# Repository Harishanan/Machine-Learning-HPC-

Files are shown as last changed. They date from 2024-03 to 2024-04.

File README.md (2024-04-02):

<h1 align="center">High-Performance Computing System</h1>

## Table Of Contents
- [I. About The Project](#i-about-the-project)
- [II. Built With](#ii-built-with)
- [III. Introduction](#iii-introduction)
- [1. System Design And Architecture](#1-system-design-and-architecture)
- [2. Technology Research:](#2-technology-research)
  - [2.1 Operating System Selection:](#21-operating-system-selection)
    - [2.1.1 Install Operating System in Head Node](#211-install-operating-system-in-head-node)
    - [2.1.2 Install Operating System in Compute Node](#212-install-operating-system-in-compute-node)
  - [2.2 Power Management](#22-power-management)
  - [2.3 Network Interconnect:](#23-network-interconnect)
  - [2.4 Cooling Calculations](#24-cooling-calculations)
    - [2.4.1.	3D Model](#2413d-model)
- [3. System Construction:](#3-system-construction)
- [4. Housing and Cooling Solutions:](#4-housing-and-cooling-solutions)
  - [4.1. Original Design For The HPC Case](#41-original-design-for-the-hpc-case)
  - [4.2. Problems Encountered](#42-problems-encountered)
  - [4.3. Chosen Shell](#43-chosen-shell)
  - [4.4. Other alterations](#44-other-alterations)
  - [4.5 Design reflection and future improvements](#45-design-reflection-and-future-improvements)
  - [4.6. Time impairment](#46-time-impairment)
  - [4.7.  Material acquisition](#47--material-acquisition)
  - [4.8. Ventilation](#48-ventilation)
  - [4.9. Change in requirements](#49-change-in-requirements)
  - [4.10 Reflection](#410-reflection)
- [5. System Configuration](#5-system-configuration)
  - [5.1. Networking](#51-networking)
    - [5.1.1. Open-SSH connection](#511-open-ssh-connection)
    - [5.1.2 Network File System (NFS)](#512-network-file-system-nfs)
  - [5.2. Power on and off function in HPC](#52-power-on-and-off-function-in-hpc)
  - [5.3. CPU frequency scaling](#53-cpu-frequency-scaling)
  - [5.4 CPU Overclocking](#54-cpu-overclocking)
- [6.Software Installation](#6software-installation)
  - [6.1. PXE Server Configuration on Ubuntu](#61-pxe-server-configuration-on-ubuntu)
  - [6.2. Cluster Package Management Script](#62-cluster-package-management-script)
    - [6.2.1. Setup](#621-setup)
    - [6.2.2. Usage](#622-usage)
  - [6.3. SLURM Configuration](#63-slurm-configuration)
  - [6.4. Apptainer Configuration](#64-apptainer-configuration)
  - [6.4.1. Reasons for Using Apptainer](#641-reasons-for-using-apptainer)
  - [6.5. Configure Prometheus and Grafana](#65-configure-prometheus-and-grafana)
  - [Importance of Grafana and Prometheus in HPC Context](#importance-of-grafana-and-prometheus-in-hpc-context)
  - [6.6. Monitoring Energy Consumption and Efficiency with Prometheus](#66-monitoring-energy-consumption-and-efficiency-with-prometheus)
- [7. Task Implementation:](#7-task-implementation)
  - [7.1. How to Create Machine Learning for Predict Crypto Currencies](#71-how-to-create-machine-learning-for-predict-crypto-currencies)
  - [7.2. Implementation of Cryptocurrency Price Prediction Application](#72-implementation-of-cryptocurrency-price-prediction-application)
- [8. Performance Evaluation: Develop a strategy for evaluating HPC system performance.](#8-performance-evaluation-develop-a-strategy-for-evaluating-hpc-system-performance)
- [9. Software and OS Maintenance:](#9-software-and-os-maintenance)
  - [9.1. The Critical Role of Software and OS Maintenance](#91-the-critical-role-of-software-and-os-maintenance)
    - [9.1.1. Software Maintenance for Enhanced Performance and Reliability:](#911-software-maintenance-for-enhanced-performance-and-reliability)
    - [9.1.2. OS Maintenance for Stability and Security:](#912-os-maintenance-for-stability-and-security)
    - [9.1.3. Impact of Maintenance on Software Complexity and Maintenance Performance:](#913-impact-of-maintenance-on-software-complexity-and-maintenance-performance)
  - [9.2. Setting Up a System for Software and Operating System Updates Using Cron and Git](#92-setting-up-a-system-for-software-and-operating-system-updates-using-cron-and-git)
  - [9.3. Create Man Page](#93-create-man-page)
- [10. Conclusion](#10-conclusion)
- [IV. References](#iv-references)
- [V. Authors](#v-authors)

# I. About The Project
The provided documentation outlines the comprehensive process undertaken by Team 0 for the design of a High Performance Computing (HPC) system as part of the Advanced Computer Engineering Module for the Computer Engineering Program at the University of Greenwich for the academic year 2023/24. This report guides the reader through a detailed step-by-step procedure encompassing both hardware and software aspects of the project. By following this documentation, readers will gain insights into the systematic approach employed by the team, enabling them to replicate and create their own HPC systems.  

The video documentation link can be found [here](https://www.youtube.com/watch?v=lD17i18koeo)

# II. Built With
- [Ubuntu](https://ubuntu.com/)
- [OpenSSH Server](https://ubuntu.com/server/docs/service-openssh)
- [Netwrok File Storage](https://ubuntu.com/server/docs/service-nfs#:~:text=NFS%20allows%20a%20system%20to,if%20they%20were%20local%20files.)
- [Slurm](https://slurm.schedmd.com/documentation.html)
- [Apptainer](https://apptainer.org/)
- [Grafana](https://grafana.com/)
- [Prometheus](https://prometheus.io/)
- [Python](https://www.python.org/)
- [Keras](https://keras.io/)
- [Scikit-learn](https://scikit-learn.org/stable/)
- [Pandas](https://pandas.pydata.org/)
- [Numpy](https://numpy.org/)
- [Yahoo Finance](https://finance.yahoo.com/quote/ORGN/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)

# III. Introduction

HPC (High Performance Computing) involves combining the computational capabilities of multiple computers to achieve significantly greater performance than individual systems. It can be referred as Cluster Computing, where a network of two or more computing devices collaborates towards a shared computing objective. This network operates on the principle of parallel processing, which entails distributing complex tasks among two or more processors (CPUs) to expedite their execution.

This documentation outlines the procedures undertaken to construct a comprehensive HPC system utilizing five motherboards, with one serving as the head node and four as compute nodes. The HPC is intended to run a cryptocurrency prediction application capable of forecasting Bitcoin, Ethereum, and Binance Coin (BNB) prices using its datasets. Additionally, it provides a detailed, step-by-step guide for configuring services and necessary configuration files to facilitate parallel processing and establish connections between nodes.

# 1. System Design And Architecture 

Before commencing the project design process, a comprehensive file containing all specifications was compiled. This file proved invaluable throughout the project, aiding in power and cooling calculations and enhancing our understanding of the system. [Specification of all the components can be found here!](hardware.md)

Initially, a design concept was developed, featuring two cases where motherboards were stacked vertically, each housing five motherboards. These motherboards would be powered by a 750W Power Supply Unit (PSU). Additionally, this design would be connected to a Single Board Computer (SBC), serving as the head node. Figure 1 illustrates the initial design idea.

<div align="center">

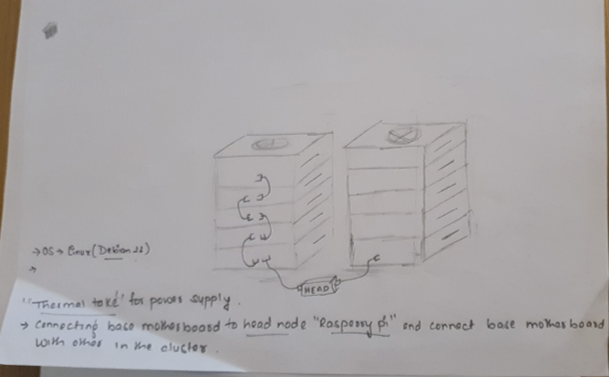
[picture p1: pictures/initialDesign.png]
Initial_Design_Sketch
<br>
      <b>Figure 1: Initial Design Sketch</b>
      <br>

</div>

But the initial idea was dropped, as it was realised that single board computer is not required, as motherboard with a wifi adapter was powerful than a single board to work as a head node. because of the time constraint, only one case was designed with 5 motherboards, and PSU was also changed because of technical issues. Therefore the design was finalised which is similar to the initial idea but only one case with five motherboard were used and the position of fans were moved to the side  which is much efficient place which will be discussed below. The final design is depicted in figure 2.

However, the initial concept was abandoned upon the realization that a single motherboard with a Wi-Fi adapter was more powerful compared to a single board computer for serving as the head node. Due to time constraints, only one case was designed to accommodate five motherboards, and the PSU was replaced due to technical challenges. Consequently, the finalized design closely resembled the initial idea, with a single case housing five motherboards. Additionally, the positioning of fans was relocated to the side, which was deemed more efficient. The final design is depicted in Figure 2.

<div align="center">

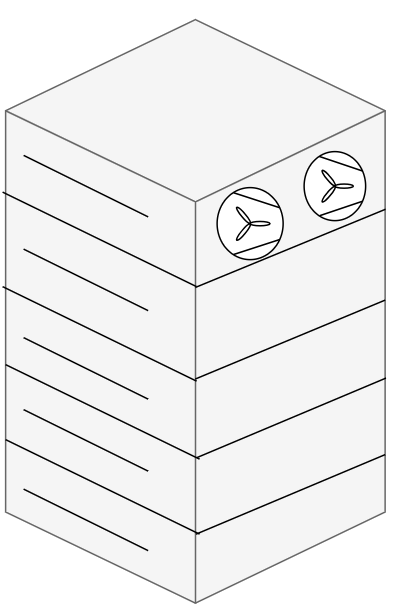
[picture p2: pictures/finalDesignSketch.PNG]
Final_Design_Sketch
<br>
      <b>Figure 2: Final Design Sketch</b>
      <br>

</div>

Once the basic structure of the HPC was conceptualized, technical research was initiated to gather essential information and conduct necessary calculations.

# 2. Technology Research: 

## 2.1 Operating System Selection: 

Initially, an attempt was made to determine which operating system the ASUS CS-B motherboard supports. However, the information available suggests that the ASUS CS-B is only compatible with Ubuntu 13.10, as indicated in the provided image.

Os
Figure 3: OS Compatibility of Asus CS-B 

### 2.1.1 Install Operating System in Head Node

1. Once the operating system was determined, below steps are followed to install ubuntu desktop 13.10:
      - Downloaded the Ubuntu Desktop from the official Ubuntu website (https://old-releases.ubuntu.com/releases/13.10/). As Intel processor is used, PC (Intel x86) desktop image is chosen when downloading the image.
      - Created a bootable USB drive using Rufus.
      - Booted the motherboard from the USB drive.
      - Followed the installation wizard to install Ubuntu Desktop on the system.

                  sudo apt update                                           
            
                  sudo apt upgrade
    
- The head node serves as a central control unit in an HPC environment, orchestrating and managing the entire cluster. Its primary purposes include task scheduling, resource allocation, and overall coordination of computational tasks within the cluster. By installing      the Ubuntu Server and setting the default target to multi-user mode optimize resource allocation, conserving RAM and CPU resources by eschewing unnecessary graphical sessions. This ensures that the head node operates efficiently, enabling it to efficiently manage and    oversee the computational workload of the entire HPC cluster.
  
            To install Ubuntu Server  : sudo apt install ubuntu-server
            To disable GUI            : sudo systemctl set-default multi-user.target
     
Although the documentation states that the ASUS CS-B motherboard can only run Ubuntu 13.10, a brief test was run to see how the motherboard would react to installing Ubuntu 24.04 (Nobel Numbat), a more recent version of the operating system. The Ubuntu 24.04      
operating system ran on the system very well, with no noticeable glitches. This surprising finding prompted more investigation into the motherboard's compatibility with the latest Ubuntu versions. 
Although documentation indicates otherwise, one plausible explanation for Ubuntu 24.04's successful running on the ASUS CS-B motherboard could be the hardware compatibility enhancements included in later Ubuntu editions. The Ubuntu operating system is continuously improved and optimised by its developers throughout time to improve compatibility with a wider variety of hardware setups. Because of this, more recent versions of Ubuntu might by nature support a greater range of motherboards, including the ASUS CS-B. Moreover, improvements in system libraries, kernel updates, and device drivers in Ubuntu 24.04 can also be responsible for its smooth operation on the ASUS CS-B motherboard. These updates might take care of any compatibility problems that earlier motherboard models might have had, making it possible to use current Ubuntu editions more smoothly.

After noticing that Ubuntu 24.04 operated steadily on the ASUS CS-B motherboard, the group chose to switch from Ubuntu 13.10 to this more recent version. This choice was driven by the goal of utilising Ubuntu 24.04's most recent software features, security updates, and hardware compatibility changes to provide the best possible computing environment for the team's activities.

### 2.1.2 Install Operating System in Compute Node

The process of installing the operating system on a compute node is similar to that of the head node, with the exception that it is not required the installation of Ubuntu Server specifically.

## 2.2 Power Management

   Following a thorough examination of individual components, research has been conducted to determine the optimal power distribution among them. Initially, the plan was to utilize two 750W Power Supply Units (PSUs). However, due to technical malfunctions in one of the PSUs, the decision has been made to employ smaller PSUs for each motherboard separately. The power consumption of each hardware component is provided below for reference.
  
   |      Components        |     Power Consumption (approx)       |       Description        |
   |------------------------|-----------------------------|--------------------------|
   |Asus CS-B Intel Core i3 4th Gen | 25W - 40W       | CPU Power Management can be handeled directly from BIOS. It provides subitems that allows to manipulate the CPU ratio and feature.|
   |SAMSUNG V-NAND 500GB SSD| 3W (Active), 50mW (idle)|Each Motherboard will be connected to one of this SSD which can be powered by a same PSU.|  
   |NVIDIA QUADRO           |    45W (Max.)           |Only one of the GPU will be used in the entire system which will be connected to the head node. |        

   |Power Supply Unit (PSU)| Capacity | Description|
   |---|---|---|
   |FSP220-50LC|220W (total output) | This PSU has a maximum wattage of 60W. And the sum of the power requirements for all the components connected to the PSU should not exceed 220W. |

* Active Power Consumption:

        CPU: 25W - 40W
        SSD: 3W
        GPU: 45W
        Total Active Power Consumption = CPU + SSD + GPU
        = (25W - 40W) + 3W + 45W
        = 73W - 88W

* Idle Power Consumption (Assuming SSD and GPU are in idle state):

* Active Power Consumption:

        CPU: 25W - 40W
        SSD: 3W
        GPU: 45W
        Total Active Power Consumption = CPU + SSD + GPU
        = (25W - 40W) + 3W + 45W
        = 73W - 88W

* Idle Power Consumption (Assuming SSD and GPU are in idle state):

* Power Supply Unit (PSU) Capacity:

        Total Output Capacity: 220W
        Maximum Wattage: 60W

Therefore, a single PSU in our system will be connected to one motherboard, one SSD, and one graphics card. The total power consumption of the system should not exceed the PSU capacity.

The system is expected to consume between 73W - 88W during active use and between 25.05W - 40.05W when idle. Although a single 220W PSU could theoretically handle the load for two motherboards, practical constraints like cable and port limitations restrict each PSU to power only one motherboard in our setup

## 2.3 Network Interconnect:

There are several interconnect technologies available for establishing connection in a cluster computing with their own strength and specefic use-cases. Some of them are :

1. **Infiniband** : Computer Networking communication standard used in high-performance computing that features high throughput and very low latency. It supports Remote Direct Memory Access(RDMA), which means the ability to access host memory directly without CPU intervention. Infiniband is widely used in supercomputer clusters and it is preferred network interconnection technology for GPU servers.
2. **NVIDIA NVLink** : World's first high-speed GPU interconnect technology that can connect two graphics card , with low latency, and high bandwidth. It is ideal for the system that uses NVIDIA graphics card, such as those in deep-learning and GPU accelerated computing. It is not best option for our project,as it is only compatible with NVIDIA graphics card and we will be using intel graphics card for our HPC.
3. **Intel Omni-Path Architecture(OPA)** : OPA is communication architecture developed by intel which aims for low communication latency, low power consumption and a high throughput. It is often used for HPC application with Intel processor. OPA directly competes with infiniband.
4. **Ethernet** : Ethernet is one of the commonly used interconnect technology because of its versatility, scalability and compatibility.It migh not provide same low-latency level as specialised interconnect like infiniband but it provides various speed, ranging from 10 megabyte to 100 gigabyte per second.    

The type of interconnect technology one needs lies on what kind of system they are building and what kind of interconnect is compatible with the system. For our system, specefication and hardware is given above.

For this project, Ethernet cables will be utilized due to their accessibility and sufficient speed for project requirements. These cables will serve dual purposes: data transfer and network bridging. The motherboard provided includes two Ethernet ports, both of which will be utilized for interconnecting nodes.

The head node will establish connections with all other nodes via a switch. Two switches will be employed: one for interconnecting all nodes to facilitate data transfer, and the other to distribute internet connectivity from the head node to all compute nodes. 

By default, one of the ports is enabled. However, to activate the second port, users must adhere to the following steps:

            Reboot the motherboard 

            Press the 'F2' or 'Del' button to access the BIOS settings 

            Navigate to Advanced settings using arrow keys.

            Proceed to Network Interface Stack Setting

            Enable the Second Interface named "Retalke Interface" (most of the cases, name may vary)

            Esure that your "Intel Interface" is also enabled.

Once the steps are followed and both interfaces are activated, users can proceed to configure each interface to perform specific tasks. Detailed instructions can be found in the following link: [Configuring Interface using Nm-Connection-Editor](https://github.com/TeachingMaterial/ace-2023_-team-0/tree/documentation/nm-connection-editor-Harishanan)

Ethernet cables were manually crimped for this project, adhering to the Registered Jack 45 (RJ-45) standard. The figure 4  illustrates the color standard for RJ-45 cables..
<div align="center">

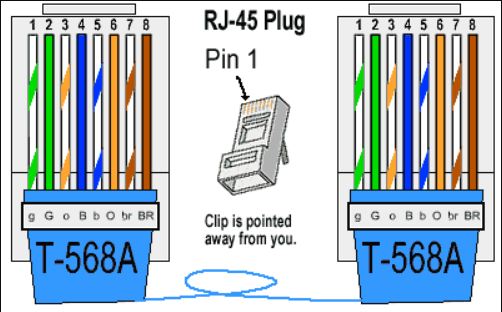
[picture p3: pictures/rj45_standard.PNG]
RJ-45 Standard
<br>
      <b>Figure 4: RJ-45 Standard</b>
      <br>
</div>

Step wise Step  process is shown in figure 5 below:
<div align="center">

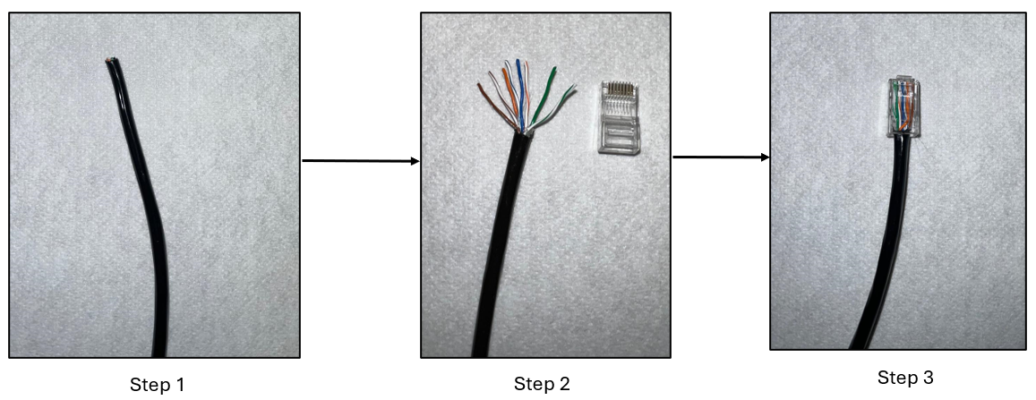
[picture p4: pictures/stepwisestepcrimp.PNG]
Ethernet-Crimp
<br>
      <b>Figure 5: Step by Step Ethernet Cimp</b>
      <br>
</div>

System is expected to consume between 73W - 88W during active use and between 25.05W - 40.05W when idle. Although a single 220W PSU could theoretically handle the load for two motherboards, practical constraints like cable and port limitations restrict each PSU to power only one motherboard in our setup

## 2.4 Cooling Calculations

Cooling calculations were conducted to determine the necessary airflow for ordering the appropriate fan. This involved performing a simple arithmetic calculation, the details of which can be found in the [this file here.](coolingcalculation.md). 

### 2.4.1.	3D Model 
 The selection of the fan was made with careful consideration of various factors, and a dual-fan system was chosen. Two fans are positioned at the front of the case to intake cool air, while another two are situated at the back to expel hot air as depicted in Figure 1. This configuration creates an airflow pattern that helps maintain optimal temperatures for all components.

   Additionally, the CPU fan, which is attached to the motherboard, provides active cooling for the CPU. Moreover, the GPU and power supply unit also have built-in fans for additional cooling.
  <div align ="center">

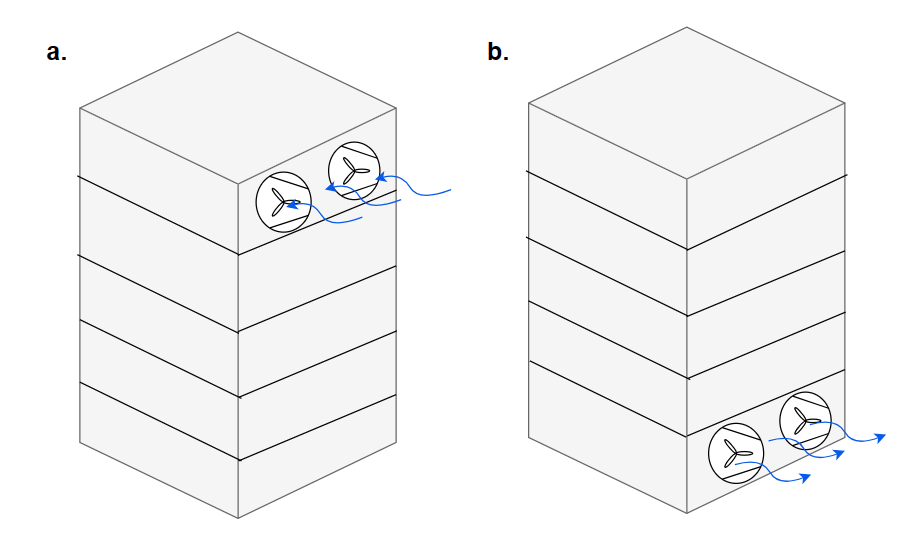
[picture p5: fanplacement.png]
Fan Placement
   <br>
   <b>Figure 6: 3D Model of Case with the fan where a) represents the front 3D view and b) represent the back 3D view </b>
   <br>
  </div>

# 3. System Construction:

Following the completion of all technical research, a preliminary outline for the basic system construction was created. This step was crucial to ensure that once the case was constructed, the components could be assembled in each shelf according to the designated layout. Notably, since the head node includes a GPU whereas the compute nodes do not, additional clearance was required to prevent overcrowding and ensure proper placement of the motherboard. The initial design for a shelf, which encompasses the motherboard, PSU, and SSD, is depicted in the figure 7 below.

  <div align ="center">

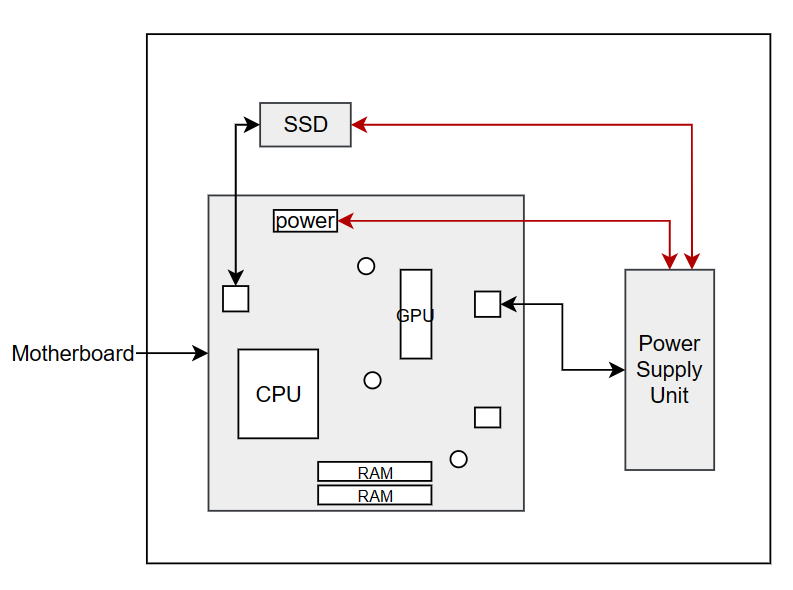
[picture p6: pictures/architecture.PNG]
Architecture
 <br>
   <b>Figure 7: 2D Structure of the shelf with all the components.</b>
   <br>

</div>

Each motherboard was equipped with a 500 GB SSD and 2 * 8 GB RAM, providing sufficient resources for efficient task execution. With four compute nodes in use, this configuration ensures optimal performance. Additionally, the head node can leverage the resources of all nodes simultaneously when executing tasks.

During the layout creation process, careful consideration was given to various requirements such as cooling, power supply, placement dimensions, and more. All calculations pertaining to these requirements have been documented in detail below.

# 4. Housing and Cooling Solutions: 

## 4.1. Original Design For The HPC Case
The original design for the case consisted of 3D printing of all components needed. This included the shelves, floor, roof, and side/back panels of the case. Multiple aspects have to be considered when designing the case such as the components requirements, ventilation, and accessibility. All original shelf and case piece that have been uploaded were designed to be durable and well ventilated and were easily connected together using a pin system

## 4.2. Problems Encountered
While waiting to receive the initial components from 3d printing I was informed that it would take to long to 3d print all my required components as there were many other students looking to 3d print components at this time Aswell. To solve this issue, we decided to order the shell of our case and print the brackets and laser cut the shelves as well as the front and back panels in stead of printing all the components

## 4.3. Chosen Shell  
The case we ordered was a 21U tall server racking system which was perfect for the purpose of our projects. It came with slots all down the left and ride side of the case which ensured enough ventilation for the fans to disperse the heat 

<div align="center">

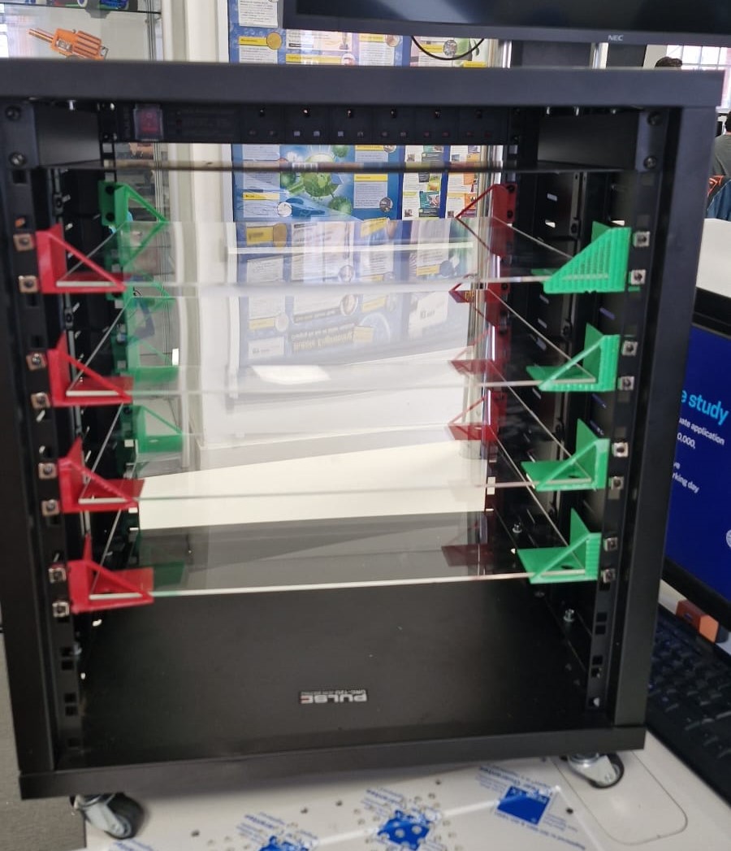
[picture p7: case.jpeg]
Shell
<br>
<b>Figure 8:Case</b>
<br><br>

</div>

The 1U brackets were 3d printed in order to hold the acrylic shelves that were laser cut. They were mounted in the holes that were ment for the racking system of the case. An extension cord was placed at the back and mounted to the top of the case. Whis acted as a way to limit the amount of cables that would exit the case. Instead, we could power each of the motherboards power sources internally 

<div align="center">
  
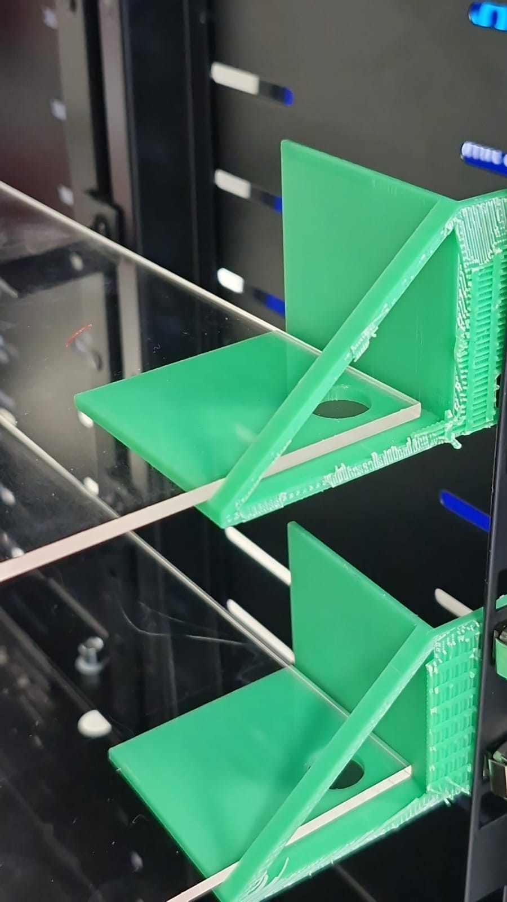
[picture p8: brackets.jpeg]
<br>
<b>Figure 9:3D printed brakets </b>
<br><br>

</div>

The front and back of the case was laser cut in acrylic with 120x120 fan holes at the base and the top in order to mount the fan to then in a way that allowed them to get a strong enough air pull. Hence the small circles that fill the 120x120 frame. the back panel was made to be slightly smaller to allow room for the extension cord 

<div align="center">

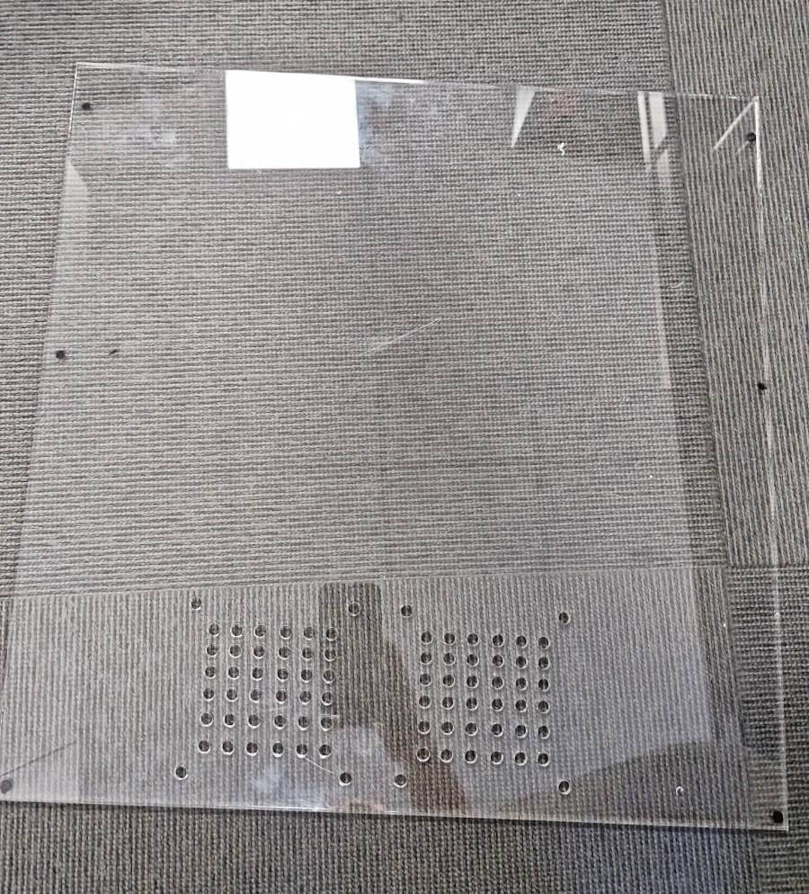
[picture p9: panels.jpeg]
<br>
<b>Figure 10:3D back panel of case  </b>
<br><br>

</div>

## 4.4. Other alterations
Rubber feet will be used on the motherboards and the SSDs to limit the directs contact onto the shelves to allow air underneath the boards when necessary. The extension cable will run down the side of the case into an outlet. The power button will drill through the roof of the case to allow Instant power to the application we have also decided to cover the back of the case to limit the light inside the case to utilize the led fans. All power supply will plug directly into the extension cord build into the case

## 4.5 Design reflection and future improvements 
During the course of this assignment there have been a few development problems and issues that arose in regard to the specific design of the case such as the time impairment, material acquisition, ventilation and change in requirements. In this report I will discuss how each of these problems were analyzed and resolved to display a design that fit the requirements of the projects while also remaining affordable and simple to construct.

## 4.6. Time impairment 
The first and possible largest issue we faced in constructing the case was time. As we had a fixed amount of time to build and submit the Hpc the case had to be completed in about a month and a half. My first idea was 3D printing the part required to build the frame/shelfing unit. After sending my designs of to be printed I was told that all part would take over 80 das as there was over 65 pieces to print along with other student needing to use the printing facilities as well.to work around this problem I decided that purchasing a frame could be cheaper and less time consuming as well as having more stability. This way I could focus more on altering the internal of the case as well as making a front and rear for the frame. This cut the time to create a case by at least a month allowing more time for alterations if need be 

## 4.7.  Material acquisition 
An issue arose with the materials as some materials were ordered before the time issues were realized. This issue was fixed by ordering the correct components and altering the lengths of some of the cables needed like the ethernet cable and the power cable along with some cable management. I mention these issues as it highlighted the need to double-check the design before ordering any components as well as communicating with my teams to avoid these mistakes happening in the future.

## 4.8. Ventilation
The ventilation of the case was considered from the very beginning as it essential to keep the system cool under prolonged periods of time.  With 5 motherboards being used in sync I decided to go with a 2 in 2 out fans system. 2 fans would take air in at the top front of the case and 2 would blow air out of the case at the bottom rear. This would allow decent air flow that would keep a steady current around the case. Temperature sensors inside the case can monitor how hot the components get and alert the user if the temperature exceeds the recommended limit.

## 4.9. Change in requirements 
Throughout the course pf this project there were a number of alterations that needed to be made to counter errors in judgement as well as new components that needed to be added to achieve complete networking between the boards. By altering the size of the shelves and by utilizing the space in the side of the case for storing the wires, all new components and power sources fit as needed 

## 4.10 Reflection 
If I were to design this case again, I believe there are a few changes that could be made. I think the biggest change I would make is I would have made holes across the laser cut shelves as it would increase the ventilation in the case however if I did this, I would make the shelf out of wood as with to many holes cut the structural integrity would be compromised and they may not be able to hold the components at the current thickness. By changing the material to wood and increasing the thickness of the shelves, adding the holes will not impair the performance. It is important to keep in mind the ultimate stress point and the fracture point of the material used as well as the elastic point. The brackets that were built were perfectly fit for purpose so I will utilize them for similar case frames in the future and if given the opportunity to improve this case

# 5. System Configuration

## 5.1. Networking
To enable parallelisation in HPC, networking must be established between the head node and compute nodes. Therefore, this section will discuss how the network is established in this project's HPC and will also discuss components such as IP address configuration, network topology, and network bridging in more detail. As an introduction, for this networking setup, a star networking topology, static IP configuration and nm-connection editor have been used and will be discussed in more detail below. Note: In the HPC, the operating system is downloaded separately on each node.

[Step by Step Configuration File Can be Found Here](nm-connection-editor.md)

Through this successful networking implementation, future works such as SLURM configuration, Wake On LAN, OpenSSH and many more can be enabled.

### 5.1.1. Open-SSH connection

OpenSSH, or Open Secure Shell, is an open-source implementation of the SSH protocol. It provides secure communication between two or more computers over an unsecured network, ensuring data exchange confidentiality and integrity. OpenSSH is widely used in Linux and other Unix-like operating systems as the standard SSH implementation for remote administration, secure file transfer, and tunnelling other network services.

In this project, Secure Shell (SSH) is employed to establish secure connections between all nodes. The OpenSSH server facilitates access from one node to another, enabling seamless communication and interaction between systems. OpenSSH is an essential component in configuring servers such as NFS and SLURM, ensuring secure and encrypted communication channels for data transfer and remote management tasks.

[Step by step configuration guide available here!](openssh.md)

### 5.1.2 Network File System (NFS)
The Network File System (NFS) is a networking protocol designed for distributed file sharing. A file system organizes and stores data in the form of files, typically on Hard Disk Drives (HDDs) or Solid-State Drives (SSDs). NFS operates on a similar principle, allowing files to be stored and accessed over a network, enabling multiple devices within the same network to retrieve and share data.

NFS is a widely utilized protocol for file sharing servers, offering compatibility across a broad spectrum of operating systems. In this project, NFS will play a crucial role in facilitating seamless file sharing among all client nodes. In this project, the functionality of NFS can be illustrated using a visualization similar to Figure 1:
<div align = "center">

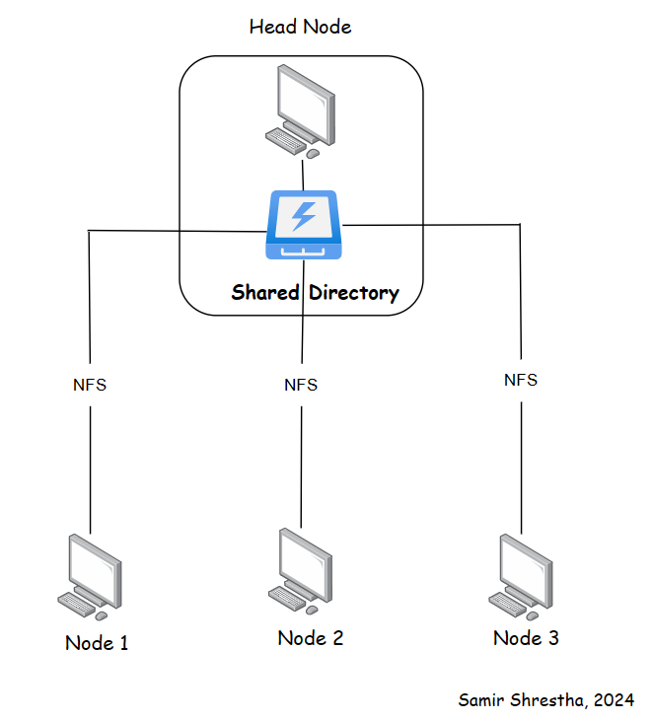
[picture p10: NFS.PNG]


<p> Figure 11. Network File Sharing </p>
</div>

In this representation:

- The "Head Node" hosts a shared directory containing files.
- The "Client Node" connects to the File Server using NFS.
- The shared directory is mounted on the Client Node, allowing  seamless access to files.
- Applications running on the Client Node can interact with the shared files through the mounted directory.

Step by Step NFS configuration Guide Can be found here: [NFS Configuration](NFS.md)

## 5.2. Power on and off function in HPC

Due to failures experienced with the power-on button for the entire HPC system, the strategy was changed to power the HPC on and off. In this project, a bash script was created using Wake-on-LAN communication and OpenSSH. Initially, the HPC's head node will be turned on using the power-on button. Afterwards, to turn on the compute nodes, a bash script will be run, which turns on the other compute nodes at intervals. Through this method, the compute nodes can be successfully powered on, allowing the whole HPC system to function. Then, to turn off all the compute nodes, the OpenSSH function was incorporated into the script, with the sudo shutdown command for all compute nodes. Through this, it is possible to turn off the entire compute nodes. Finally, to turn off the head node, one can press the power button or enter a separate sudo shutdown command for the head node.

[Step by Step Configuration File Can be Found Here](power-on-off.md)

## 5.3. CPU frequency scaling 
The Linux kernel offers CPU performance scaling via the CPUFreq subsystem, which defines two layers of abstraction:

- Scaling governors implement the algorithms to compute the desired CPU frequency, potentially based off of the system's needs.
- Scaling drivers interact with the CPU directly, enacting the desired frequencies that the current governor is requesting (wiki.archlinux.org, n.d.). 

A script is written to control the cpu frequency scaling which can be found [here](CPU_Scaling_Governor) 

CPU performance scaling enables the operating system to scale the CPU frequency up or down in order to save power or improve performance. Scaling can be done automatically in response to system load, adjust itself in response to ACPI events, or be manually changed by user space programs.

## 5.4 CPU Overclocking 

Overclocking involves increaing the CPU's clock speed beyond its predefined limits set by the manufacturer. Typically utilized to enhance performance and processing capabilities, this technique increases the frequency at which the CPU operates, measured in cycles per second (Hertz). With increased clock speeds, the CPU executes operations at a quicker pace than its standard rate, resulting in improved performance for tasks such as gaming, video editing, and handling intensive computational workloads. 

However, Overclocking also causes some issues which should be calculated in the beginning. Increased clock speed may cause more heat, which leds CPU to higher temperatures, which might damage the component if not handeled properly. For this project overclocking might not be needed but there will be an option to enable the overclocking if needed.

The Steps which can be followed to overclock the CPU can be found [here!](overclock.md)

# 6.Software Installation

## 6.1. PXE Server Configuration on Ubuntu 

PXE stands for Preboot Execution Environment is a set of guidelines that allow a computer to boot an operating system (OS) via a network connection. In this project, the PXE Server was initially considered but ultimately not utilized due to technical challenges. Despite multiple attempts to configure PXE, the plan had to be abandoned due to technical issues. Instead, the group opted for a Static Interface Configuration approach for data sharing. Even though PXE booting was unsuccessful, the configuration details of the PXE Server were documented for future reference.

The basic topology for PXE Server is shown below:
<div align="center">

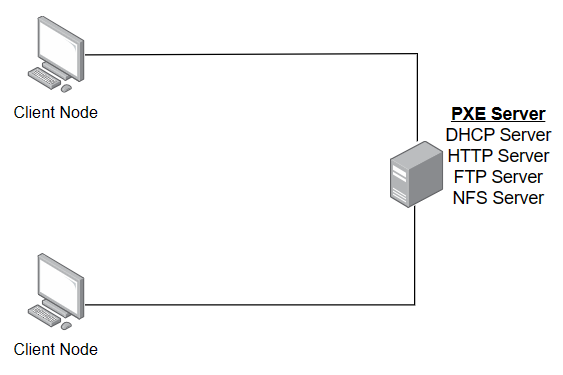
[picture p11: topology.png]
access SSH
<br>
<b>Figure 12: Basic Topology for PXE</b>
<br><br>
</div>

The packages used for the configuration are given below in table:

| Protocol | Package Name | Description |
|---|---|--- |
|  DHCP server  | dnsmasq | DHCPD stands for Dynamic Host Configuration Protocol whcich allocates IP address to Client Node from a predefined pool. This ensures that the client nodes can communicate and access network resources.
|  TFTP server  | tftpd-hpa | TFTP stands for Trivial File Transfer Protocol which is used for transfering files between devices on a network. It is a lightweight protocol which lacks advanced features like authentication and directory listing. 
|  FTP Server | vsftpd | File Transfer Protocol is similar to TFTP which supports various commands for navigating directories, uploading, downloading, renaming, and deleting files on the server. 
| HTTP | apache2 |HTTP is a flexible and extensively used protocol that offers a convenient way to communicate and transfer data within cluster computing setups.
| NFS | nfs-kernel-server | [NFS Configuration](NFS.md)

[Step by Step Configuration Guide is provided here!](pxeconfig.md)

## 6.2. Cluster Package Management Script
A bash script is written to automate the process of synchronizing software package installations across a distributed computing environment. It addresses the operational challenge of maintaining consistent software versions across all nodes within a cluster. 

### 6.2.1. Setup
Ensure that SSH keys are configured for password-less access to all client nodes. This is a prerequisite for the script to execute commands remotely without manual intervention.

### 6.2.2. Usage
The script supports two primary operations: installation and uninstallation of software packages. It is invoked from the command line as follows:

```sh

./packageManager.sh -i|-u <package_name>
Options:

-i: Install the specified package across all nodes.
-u: Uninstall the specified package across all nodes.

```
The script can be seen [here](PackageManagerScript.md) with explanation

## 6.3. SLURM Configuration

SLURM, an acronym for Simple Linux Utility for Resource Management, is an open-source workload manager developed for supercomputers and Linux-based cluster systems. It offers three primary functions: 

1. It allocates both exclusive and non-exclusive access to compute node resources from a central head node, allowing tasks to be executed efficiently.
2. It furnishes a structured framework for initiating, executing, and overseeing tasks across a designated set of allocated nodes.
3. It resolves resource contention by administering a queue of pending work, ensuring fair access to resources among multiple users or processes.  

The primary commands for submitting, allocating, and monitoring jobs in SLURM are outlined as follows:

1. **sbatch**: Employed to submit batch jobs, allowing users to send job requests to the SLURM scheduler. Job parameters and requirements are defined within a job script, and SLURM schedules and executes the job accordingly.

2. **salloc**: Facilitates interactive resource allocation, enabling users to acquire compute resources in real-time. Once resources are allocated, users can execute commands within this dedicated resource environment.

3. **srun**: Used to execute parallel tasks within allocated resource environments, whether obtained interactively through `salloc` or as part of a batch job submitted with `sbatch`. It manages the execution of parallel tasks across specified nodes.

4. **squeue**: Utilized for monitoring the status of jobs in the SLURM job queue, providing details such as job ID, user, status, and resource utilization. This allows users to monitor job progress and identify queued or running jobs.

5. **scancel**: Enables users to terminate running or queued jobs within the SLURM job queue by specifying the job ID(s) of the targeted jobs to be canceled.

6. **scontrol**: Used for modifying or querying the configuration and state of the SLURM cluster, granting users the ability to manage SLURM resources by configuring nodes, partitions, and accounts, as well as accessing information about jobs and nodes.

These commands serve as essential tools for effectively interacting with SLURM and managing job execution on high-performance computing clusters.

[Step by Step Configuration File Can be Found Here!](slurm.md)

## 6.4. Apptainer Configuration

Apptainer, formerly known as Singularity, is a containerization platform designed to bring containers and reproducibility to scientific computing and the high-performance computing (HPC) environment. Apptainer is specifically optimized for HPC systems, providing a seamless way to package entire scientific workflows, software, libraries, and even data into a single file (Kurtzer et al., 2017).

## 6.4.1. Reasons for Using Apptainer

| Benefit | Description | Reference |
|---|---|---|
| **Portability** | Apptainer containers can be executed across different computing environments consistently, ensuring that workflows are reproducible across different HPC systems. | Muster et al., 2018 |
| **Compatibility** | Designed with HPC environments in mind, Apptainer does not require root privileges, aligning with the security policies of most HPC centers. | Doe, 2019 |
| **Efficiency** | Containers encapsulate all dependencies, streamlining installations and avoiding software version conflicts. | Smith, 2020 |
| **Reproducibility** | Packaging software with its dependencies ensures computational work is reproducible, crucial for scientific research validation. | Lee and Thompson, 2021|

Below, you can find details on how Apptainers function with images and how they can be configured:

[Learn More about Apptainer and How to Configure apptainer](configure_apptainer.md)

## 6.5. Configure Prometheus and Grafana

Grafana is an open-source analytics and monitoring solution that provides powerful and elegant visualizations of complex data. It is widely used for graphing time series data, and its dashboard offers rich features for displaying metrics through graphs, charts, and alerts. Prometheus, on the other hand, is an open-source monitoring system with a focus on reliability and simplicity. It collects and stores its metrics as time series data, including features such as precise alerting based on complex rules. When used together, Prometheus acts as a powerful data source that feeds Grafana with real-time metrics, enabling detailed analysis and monitoring of systems and applications. This combination is especially potent in HPC environments where managing and understanding the performance and health of computing resources is critical for efficiency and effectiveness.

## Importance of Grafana and Prometheus in HPC Context

| Feature | Importance in HPC |
|---|---|
| **Performance Monitoring** | Enables real-time tracking of computing tasks and resource utilization, crucial for optimizing the performance of high-speed computing tasks. |
| **Resource Optimization** | Identifies underutilized or overburdened resources, ensuring optimal allocation for computational jobs, thus enhancing efficiency and throughput. |
| **Scalability** | Adapts to the dynamic nature of HPC environments, capable of monitoring thousands of nodes and services, thus supporting growth without losing oversight. |
| **Fault Detection** | Offers early detection of system anomalies or failures, minimizing downtime and ensuring continuity in critical computational processes. |
| **Cost Management** | Through efficient resource management and optimization, helps in reducing operational costs, which is particularly important in resource-intensive HPC environments. |

Prometheus, an open-source monitoring and alerting toolkit, is engineered for scalability and reliability when collecting time-series data. Conversely, Grafana serves as a widely-used visualization tool that enriches Prometheus capabilities by delivering dynamic and personalized dashboards for the analysis and monitoring of data. 

Prometheus and Grafana were employed in this project for monitoring the performance of the application. These software tools were utilized for visualization purposes, enabling efficient resource allocation and scheduling. The full configuration file for these applications is provided here: [Configure Prometheus and Grafana](https://github.com/TeachingMaterial/ace-2023_-team-0/blob/dev/configure_Prometheus_Grafana.md)

## 6.6. Monitoring Energy Consumption and Efficiency with Prometheus

Energy efficiency is pivotal for both environmental sustainability and reducing operational costs in IT environments. By accurately monitoring energy use, organizations can identify inefficiencies, optimize power usage, and contribute to a more sustainable future. This documentation guides the integration of hardware sensor data with Prometheus to monitor energy consumption indirectly through temperature metrics, offering a path towards achieving these goals.

An explanation is written of how Node Exporter and lm_sensors are utilized for monitoring energy consumption ([See here](Monitor_Energy_Consumption.md))

# 7. Task Implementation:

## 7.1. How to Create Machine Learning for Predict Crypto Currencies

To predict cryptocurrency prices with machine learning, start by fetching historical data (prices, volumes, timestamps) using Yahoo Finance. Process this data, compute technical indicators (RSI, EMA, SMA), and normalize to ensure uniformity. Split the data into training, validation, and testing sets for model development and evaluation. Consider machine learning models such as LSTM for capturing long-term dependencies, and GRU for efficient sequential data handling. Fine-tune models using the validation set and assess their performance with metrics like RMSE and MAE on the test set, aiming to select the model that best captures cryptocurrency market dynamics. (<b>This needs to be rewritten</b>)

[Access the detailed step-by-step guide here](Predicting_Cryptocurrency_Prices_with_ML.md)

## 7.2. Implementation of Cryptocurrency Price Prediction Application

After initially testing the application on a laptop, the outcomes met expectations. However, upon uploading the application to the HPC, issues arose with task distribution across all nodes equally. Fortunately, these issues were addressed and resolved through the utilization of Prometheus, Grafana, and Slurm. Subsequently, the system began functioning smoothly. For detailed implementation information, please refer to the provided link below.

[Access the detailed step-by-step guide here](https://github.com/TeachingMaterial/ace-2023_-team-0/blob/dev/Implementation_of_ML.md)

# 8. Performance Evaluation: Develop a strategy for evaluating HPC system performance. 
  As the HPC system was built for this project, a series of tests were conducted to evaluate its performance. The steps and guidelines described above, including networking, power on/off functions, prometheus, Grafana, the justification for choosing operating systems and designs’ tests have demonstrated that the specific tasks or designs function very well. Due to time constraints and technical challenges, screenshots were not captured for testing purposes. However, sufficient evidence has been provided throughout this documentation to demonstrate the full functionality of the HPC system. Live demonstrations will be conducted during the VIVA session to validate the operational integrity of the HPC system. More proof has been provided in this following [link.](performance.md).

# 9. Software and OS Maintenance: 

## 9.1. The Critical Role of Software and OS Maintenance
The importance of software and OS maintenance in high-performance computing (HPC) environments is crucial due to several factors. Maintenance activities, ranging from routine updates to comprehensive system overhauls, ensure that HPC systems deliver optimal performance, security, and compatibility over time.

### 9.1.1. Software Maintenance for Enhanced Performance and Reliability:

Regular software maintenance is essential for correcting errors, improving performance, and ensuring the compatibility of HPC systems with new hardware and software technologies. It involves updating applications and system software to fix bugs, address security vulnerabilities, and add new features, thereby enhancing both performance and reliability (Pan Ming, 2003; Ahmad Salman Khan & M. Kajko-Mattsson, 2012).

### 9.1.2. OS Maintenance for Stability and Security: 

Maintenance of the operating system is equally important in HPC environments. This includes patching security vulnerabilities, updating drivers for new hardware components, and optimizing the OS for performance. Such maintenance tasks ensure that the HPC environment remains stable, secure, and capable of delivering high-performance computing resources efficiently (M. Joy, S. Jarvis, & Michael Luck, 2002).

### 9.1.3. Impact of Maintenance on Software Complexity and Maintenance Performance:

Maintenance activities also play a pivotal role in managing software complexity, which in turn affects the ease and cost of future maintenance efforts. Implementing best practices in software development and maintenance can reduce complexity, making software easier to update and maintain. This is crucial in HPC environments where the complexity of tasks and the volume of data can be very high (R. Banker, G. Davis, & S. Slaughter, 1998).

Thus, effective software and OS maintenance in HPC environments is pivotal for ensuring that these complex systems operate at their peak efficiency, remain secure, and continue to support the evolving needs of high-performance computing tasks. The maintenance process, while often resource-intensive, is essential for the long-term success and reliability of HPC systems.

## 9.2. Setting Up a System for Software and Operating System Updates Using Cron and Git

[A Detailed Guide: Step-by-Step Instructions Available Here](UpdateSystem&OS.md)
   
## 9.3. Create Man Page

The creation of manual pages, or "man pages," serves as a cornerstone in documenting software within Unix and Unix-like operating systems. Their primary purpose is to offer users, system administrators, and developers a comprehensive, accessible, and standardized documentation format. Man pages provide an indispensable quick reference for commands, system calls, configuration files, and beyond, detailing usage, options, examples, and environmental considerations. They adhere to a specific structure, ensuring information is consistently organized and easily retrievable. This standardization not only aids in quick learning and reference but also ensures documentation is readily accessible directly from the command line, eliminating the need for internet access or external resources. Beyond serving as a practical guide, man pages play an educational role, helping new users navigate the complexities of the command line and offering developers detailed insights into system programming interfaces. Additionally, they document system behaviors and configurations, contributing to a deeper understanding and more effective management of Unix-like systems. Man pages, therefore, are more than just documentation; they are an integral part of the Unix ecosystem, fostering a culture of self-sufficiency and informed usage among its user base.

[Step-By-Step Guide can be found here](CreateManPage/createManPage.md)

# 10. Conclusion 

This comprehensive documentation outlines the meticulous process of designing, constructing and deploying a High-Performance Computing (HPC) system tailored for cryptocurrency price prediction. This project not only highlights the technical process required to integrate multiple components into a cohesive and efficient computing cluster but also underscores the importance of software and operating system maintenance in sustaining system performance and security. Through the strategic use of open-source tools like Prometheus and Grafana for monitoring, along with detailed configurations for networking and power management, team 0 has successfully demonstrated the system's superior performance over conventional computing solutions. 

The reflections on design choices and the iterative improvements made throughout the project provide valuable insights into the complexities of building an HPC system from the ground up. Ultimately, this documentation serves as a valuable resource for anyone looking to venture into the realm of high-performance computing, offering a blend of technical guidance, performance evaluation strategies and maintenance practices essential for the successful operation of an HPC system.

Finally, a great thanks to our module leader, Sebastian Blair, and the University of Greenwich technical team. Special thanks to Mr. Josh from Team 0.
 
# IV. References

1. The button can be find here: https://uk.rs-online.com/web/p/push-button-switches/2099127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

2. How to install WOL : https://pimylifeup.com/ubuntu-enable-wake-on-lan/#:~:text=Wake%2Don%2DLAN%20is%20a,functionality%20through%20your%20devices%20BIOS.

3. Power button and Front panel connections : https://www.pcinq.com/how-to-connect-motherboard-front-panel-headers/
                            https://www.electronicshub.org/power-button-on-motherboard/#:~:text=Ans%3A%20The%20power%20switch%20on,for%20the%2020-pin%20header
4. https://www.diva-portal.org/smash/get/diva2:1778251/FULLTEXT03
5. https://www.sharpsightlabs.com/blog/machine-learning-hyperparameters-explained/
6. https://scikit-learn.org/stable/index.html
7. https://www.warse.org/IJATCSE/static/pdf/file/ijatcse351942020.pdf
8. https://hpc.uni.lu/infrastructure/network
9. https://dlcdnimgs.asus.com/websites/global/aboutASUS/OS/Linux_Status_report_202312.pdf
10. https://www.diva-portal.org/smash/get/diva2:1778251/FULLTEXT03
11. https://www.sharpsightlabs.com/blog/machine-learning-hyperparameters-explained/
12. https://scikit-learn.org/stable/index.html
13. https://www.warse.org/IJATCSE/static/pdf/file/ijatcse351942020.pdf
14. https://hpc.uni.lu/infrastructure/network
15. https://hpc.uni.lu/infrastructure/network
16. https://dlcdnimgs.asus.com/websites/global/aboutASUS/OS/Linux_Status_report_202312.pdf
17. https://medium.com/jacklee26/set-up-pxe-server-on-ubuntu20-04-and-window-10-e69733c1de87
18. https://www.diva-portal.org/smash/get/diva2:1778251/FULLTEXT03
19. https://www.sharpsightlabs.com/blog/machine-learning-hyperparameters-explained/
20. https://scikit-learn.org/stable/index.html
21. https://www.warse.org/IJATCSE/static/pdf/file/ijatcse351942020.pdf
22. https://hpc.uni.lu/infrastructure/network
23. https://dlcdnimgs.asus.com/websites/global/aboutASUS/OS/Linux_Status_report_202312.pdf
24. https://www.diva-portal.org/smash/get/diva2:1778251/FULLTEXT03
25. https://www.sharpsightlabs.com/blog/machine-learning-hyperparameters-explained/
26. https://scikit-learn.org/stable/index.html
27. https://www.warse.org/IJATCSE/static/pdf/file/ijatcse351942020.pdf
28. https://hpc.uni.lu/infrastructure/network
29. https://www.diva-portal.org/smash/get/diva2:1778251/FULLTEXT03
30. tps://www.sharpsightlabs.com/blog/machine-learning-hyperparameters-explained/
31.https://scikit-learn.org/stable/index.html
32. tps://www.warse.org/IJATCSE/static/pdf/file/ijatcse351942020.pdf
33. tps://hpc.uni.lu/infrastructure/network
34. tps://dlcdnimgs.asus.com/websites/global/aboutASUS/OS/Linux_Status_report_202312.pdf
35. ki.archlinux.org. (n.d.). CPU frequency scaling - ArchWiki. [online] Available at: https://wiki.archlinux.org/title/CPU_frequency_scaling [Accessed 2 Apr. 2024].
36. https://www.diva-portal.org/smash/get/diva2:1778251/FULLTEXT03
37. https://www.sharpsightlabs.com/blog/machine-learning-hyperparameters-explained/
38. https://scikit-learn.org/stable/index.html
39. https://www.warse.org/IJATCSE/static/pdf/file/ijatcse351942020.pdf
40. https://hpc.uni.lu/infrastructure/network
41. https://dlcdnimgs.asus.com/websites/global/aboutASUS/OS/Linux_Status_report_202312.pdf
42. Pan Ming (2003) The discussion about software maintenance. Information Technology.
43. Ahmad Salman Khan & M. Kajko-Mattsson (2012) Evaluating the Role of Maintenance Environment Activities in Software Handover. 2012 8th International Conference on Computing Technology and Information Management (NCM and ICNIT), 1, pp. 230-237.
44. R. Banker, G. Davis, & S. Slaughter (1998) Software Development Practices, Software Complexity, and Software Maintenance Performance: a Field Study. Management Science, 44, pp. 433-450.
45. M. Joy, S. Jarvis, & Michael Luck (2002) Maintaining your Linux OS.

# V. Authors

1. [Christopher Reily](https://github.com/chrisreilly706)
2. [Harishanan Thevarajah](https://github.com/Harishanan)
3. [Juan David Gallego](https://github.com/jjuanda19)
4. [Taufique Azad](https://github.com/taufique-06)
5. [Samir Shrestha](https://github.com/sameyr)

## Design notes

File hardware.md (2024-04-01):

# HARDWARE Components

Below are the specifications of the components utilized in this project: 

- [HARDWARE Components](#hardware-components)
  - [ASUS CS-B](#asus-cs-b)
  - [SAMSUNG v-NAND SSD 860 EVO](#samsung-v-nand-ssd-860-evo)
  - [NVIDIA QUADRO](#nvidia-quadro)
  - [TP-Link Switch - TL-SG105](#tp-link-switch---tl-sg105)
  - [External Fans](#external-fans)
  - [Power Supply Unit (FSP220-50LC)](#power-supply-unit-fsp220-50lc)
- [References](#references)

## ASUS CS-B
    
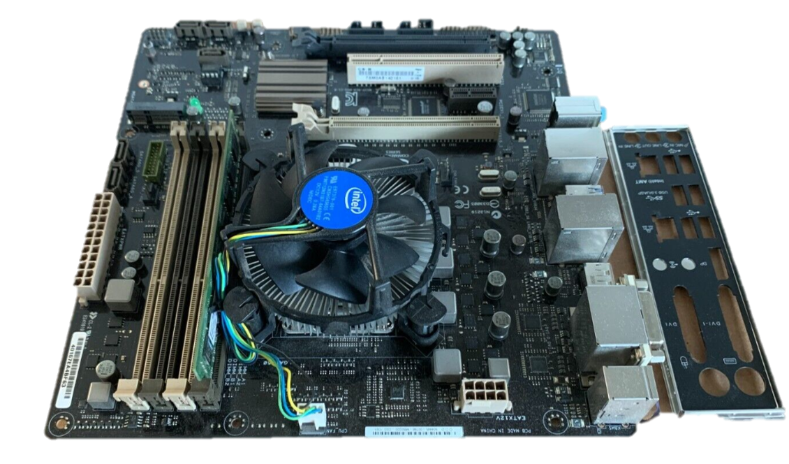
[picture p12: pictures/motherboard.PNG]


* CPU: Intel 4TH Generation Core Core i5 
  
* RAM: 2 x 8 GB DDR3 (4 Slots Available)  
 
* Internal USB: 8 x USB 2.0, 4 x USB 3.0  
  
* Intel I217LM, /Realtek 8111G, 1 x Gigabit LAN Controller

* Realtek ALC887-VD 8-Channel High Definition Audio CODEC

* Heat Sink Fan, 128 Mb Flash ROM, AMI BIOS, PnP, DMI2.0, WfM2.0, SM BIOS 2.5, ACPI 2.0a,

## SAMSUNG v-NAND SSD 860 EVO

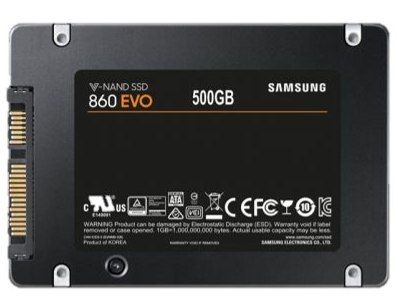
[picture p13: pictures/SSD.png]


* Capacity:	500 GB

* Core Count:	Triple-Core

* Frequency:	1,000 MHz

* Sequential Read:	550 MB/s

* Sequential Write:	520 MB/s
 
* Random Read:	98,000 IOPS

* Random Write:	90,000 IOPS

## NVIDIA QUADRO

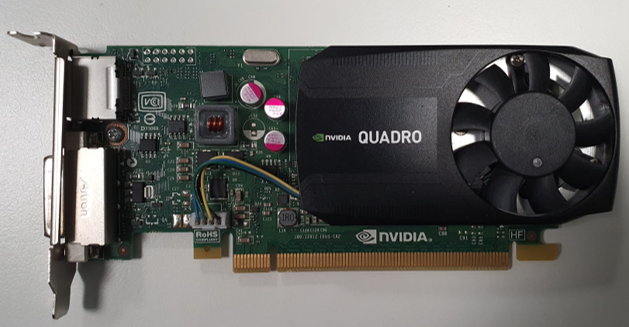
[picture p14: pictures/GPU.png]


* GPU Memory 2 GB DDR3

* Memory Interface 128-bit

* Memory Bandwidth 29.0 GB/s

* NVIDIA CUDA® Cores 384

* Thermal Solution Ultra-Quiet Active 
Fansink

* Graphics APIs Shader Model 5.0, OpenGL 4.53, DirectX 11.24, Vulkan 1.03
  
## TP-Link Switch - TL-SG105

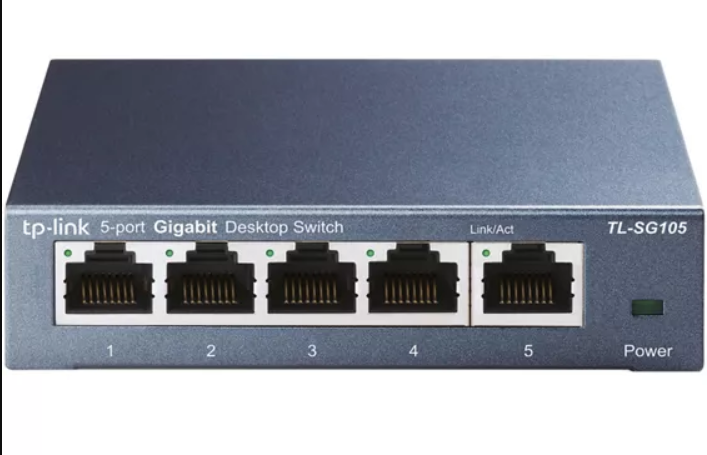
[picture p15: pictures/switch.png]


*  5 x 10/100/1000Mbps ports

* Compact design with Energy efficient Technology.

* Power Down Idle Ports

* Power Budget According to Cable Length : shorter cables would use less power because of less power degradation over their length

* Easy to use and save up to 84% of the power consumption
  
## External Fans

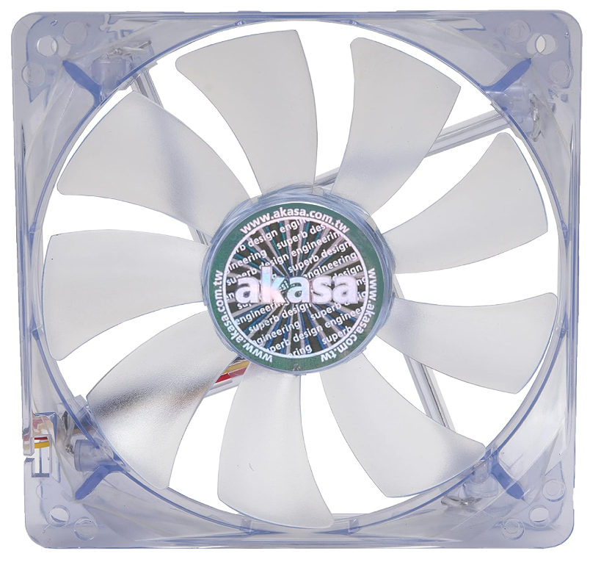
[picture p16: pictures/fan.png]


* Product Name: Akasa AK-174

* Power connector type:	3-Pin

* Voltage:	12 Volts

* Housing : Transparent, Blue LED Case 

* Fan Dimension: 120 120 25mm

* Fan speed 1700 RPM

* Airflow 59.05 CFM 100.0m3/hFan
 
* Air pressure 3.57mmH2O 
  
* Noise level 29.75 dBA
  
* Current rating: 0.18A

* Bearing type Twin Ball
  
* Fan life expectancy 50,000 hours

## Power Supply Unit (FSP220-50LC)

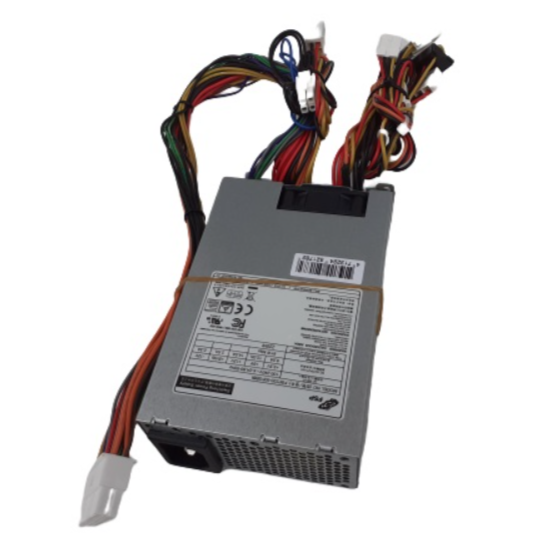
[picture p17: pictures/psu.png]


* 1 x 20-Pin Main Connector
  
* 1 x CPU 4-Pin 12V Connector

* 2 x SATA Connector

* 1 x 4-Pin Molex Peripheral Connector

* 1 x Floppy Drive Connectors:

* Dimensions (mm) : 81mm x 40mm x 150mm 

* Efficiency :	85% typical load (85 certificate)

* Input Voltage :  Full Range 110-230V

* Input Current :  4A/ 115VAC in, 2A/ 230 VAC in

* Input Frequency Range :  47-63 Hz

#  References
TP-Link Switch - TL-SG105: https://groceries.asda.com/product/mobile-phone-accessories/tp-link-5-port-gigabit-ethernet-switch-tl-sg-105/1000144744779

ASUS CS-B: https://basitcomputers.com/product/i5-4590-4th-gen-motherboard-processor-asus-q87-cs-b/

SAMSUNG v-NAND SSD 860 EVOL: https://www.techpowerup.com/ssd-specs/samsung-860-evo-500-gb.d7

External Akasa AK-174: https://www.amazon.ae/Akasa-AK-174CB-4BLB-12cm-Blue-case/dp/B000OGZ8QG?th=1

FSP220-50LC: https://www.headingpower.com/p-75-fsp220-50lc-220w-flex-atx-power-supply.aspx

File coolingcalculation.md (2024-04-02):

# Cooling Calculation 

##  1.  Caluclating Power Consumption for each component:

   *	CPU – 84 Watt  (https://www.cpu-world.com/CPUs/Core_i5/Intel-Core%20i5-4590.html )
   *	GPU – 45Watt (https://www.techpowerup.com/gpu-specs/quadro-k620.c2600 )
   *	Single Board – it is not going to generate too much power. (It is not used)
   *	RAM – 3 Watt (https://uk.crucial.com/support/articles-faq-memory/how-much-power-does-memory-use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,the%20voltage%20beyond%20XMP%20settings.)
   *	Power Supply – 132.50W
   *	SSD - 4 Watt (https://www.windowscentral.com/samsung-860-evo-review) 

##  2.	Sum up Power Consumption values for all components

      = Power Consumption (CPU + GPU + RAM + Power Supply + SSD)

      = (84 + 45 + 3 + 132.50 + 4) Watts

      = 268.50 Watt 

   Total Power Consumption for head Node is 268.50 Watt 

## 3. To Calculate Heat Dissipation in BTU/Hr:

   *NOTE: One BTU per hour is the energy needed to heat One Pound of Water to 1°F, for one hour*

   Multplying Total Power Consumption  *  3.4192  (https://www.se.com/uk/en/faqs/FA213115/#:~:text=To%20calculate%20heat%20dissipation%2C%20multiply,is%20equal%20to%20BTU%20%2F%20HR.)

      = 268.50 * 3.4192
      
      = Approx. 920 BTU/Hr

   Taking into consideration, that only head node is using GPU, the heat dissipation of compute node will be :

         = Power Consumption (CPU + RAM + Power Supply + SSD) * 3.4192

         = (84 + 3 + 132.50 + 4) * 3.4192

         = 223.5 * 3.4192

         = 764.2 BTU/hr

## 4 Requirement taken into Consideration while choosing the fan :

   * Size: Utilizing four fans of approximately 120mm, the standard dimension for case fans, is the chosen configuration.
   * Speed: should be more than 1000 RPM , so thatit can produce required airflow
   * Max Airflow:	At least. 35 CFM
   * Connector: Fans are selected to be compatible with the motherboard's fan headers, featuring a 4-pin connector.
   * Noise level: Priority is given to fans with a low noise level to guarantee quieter system operation.
  
## 5 Cooling Calculation:

   * Fan used in this project:
      
      Akasa 120mm LED Computer Fan with an airflow of approx. 59 CFM

   * Converting CFM(Cubic Feet Per Minute) to CMH (Cubic Meter Per Hour)
      
         1CFM = 1.699CMH

         59 CFM = 59 * 1.699 = 100.241 CMH

   * As we are using 4 fans, total CMH will be:

         = 4 * 102.241 CMH = 400.964 CMH.  
   
      Now lets see if the airflow provided by fan is sufficient to dissipate the heat generated by the system effectively. 

      * `Airflow (CMH) = Total Heat Dissipiation (BTU/hr) / (ΔT * 1.08)` where,
      `∆T = Change in Temperature`

      Typical change in temperature for this kind of system is 15 to 20⁰C , but as there are in-built fan present for CPU, GPU and Power supply, the change in temperature will be approx. 8 to 10 ⁰C. Therefore, Airflow needed to te system will be :

      * Required Airflow for head node(CMH) 
            
            = 920 / 10 * 1.08 
            = 85.18 CMH.

      * Required Airflow for compute node(CMH)
            
            = 764.2 / 10 * 1.08 (for head node)
            = 70.75 CMH.

      * Total Airflow required 
               
            = Airflow needed for head node + 4 * (Airflow needed for compute node)
             = 85.18 + 4 * 70.75 
             = 85.18 + 283.03
             = 368.04 CMH
  
      Therefore, the total airflow required in the system which is 360.04 CMH is less than air flow which is provided by the fan which is 400.964 CMH.

## 6. Examination

   A heat gun was employed to assess the heat dissipation of the entire system under two conditions: with the fan operational and with the fan deactivated. The result of testing is provided in Performance Evaluation Part.

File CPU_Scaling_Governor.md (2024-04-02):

# CPU Scaling Governor Management Script
This bash script provides a straightforward interface for managing CPU scaling governors on Linux systems. It allows users to display the current CPU scaling governor for each CPU and change the governor to one of the available options.

## Key Features
- Display the current CPU scaling governor for each CPU.
- Change the CPU scaling governor to one of the following options:
  - performance
  - powersave
  - ondemand
  - userspace
  - conservative
  - schedutil

## How to Use
1. Run the script in a terminal by doing (The script can be found [here](cpuGovernor.sh)):
   
```sh
./cpuGovernor

```
2. Choose one of the two options:
   - 1 to show the current CPU Scaling Governor.
   - 2 to change the CPU Scaling Governor.
     
3. If changing the governor, enter the desired governor when prompted.

## Choosing the Right CPU Scaling Governor
The choice of CPU scaling governor should be based on your system's needs and priorities, such as performance or power efficiency. Here's a brief guide to help you decide:

1. <b>performance:</b> Maximizes computational performance without regard to power consumption.
2. <b>powersave:</b> Minimizes power consumption at the expense of computational performance.
3. <b>ondemand:</b> Dynamically increases CPU speed when needed, offering a balance between performance and power usage.
4. <b>conservative:</b> Similar to ondemand but increases CPU frequency more gradually.
5. <b>schedutil:</b> Makes scaling decisions based on the scheduler's load tracking, potentially offering better efficiency.

## Factors to Consider
- <b>Workload Characteristics:</b>
1. <i>CPU Intensity:</i> If the tasks are CPU-intensive and require quick completion, then considering higher clock frequencies is necesary.
2. <i>Task Urgency:</i> If the tasks can afford slower processing times in exchange for energy savings, then lower clock frequencies is fine.

- <b>Energy vs. Performance Priorities:</b>
1. <i>Minimizing Energy Consumption:</i> If energy efficiency is a priority, a governor like ‘powersave’ may be suitable as it sets the CPU statically to the lowest frequency within operational limits.
2. <i>Maximizing Performance:</i> If performance is critical, the ‘performance’ governor may be more appropriate as it sets the CPU statically to the highest frequency within the scaling range.

##References

1. Kernel Documentation. (2017). CPU Performance Scaling. Retrieved from https://www.kernel.org/doc/html/v4.14/admin-guide/pm/cpufreq.html
2. Stack Exchange. (2018). What are the implications of setting the CPU governor to “performance”? Retrieved from https://unix.stackexchange.com/questions/439340/what-are-the-implications-of-setting-the-cpu-governor-to-performance

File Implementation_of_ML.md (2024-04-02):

# Implementation of Machine Learning Application
A Tkinter-based GUI application that facilitates user registration and login, and offers cryptocurrency price predictions for Bitcoin, Ethereum (ETH), and Binance Coin (BNB). It uses SHA-256 hashing for password security and multithreading to enhance performance during price prediction processes.

The following flow chart has been created to facilitate understanding of the application's usage.

<p align="center">
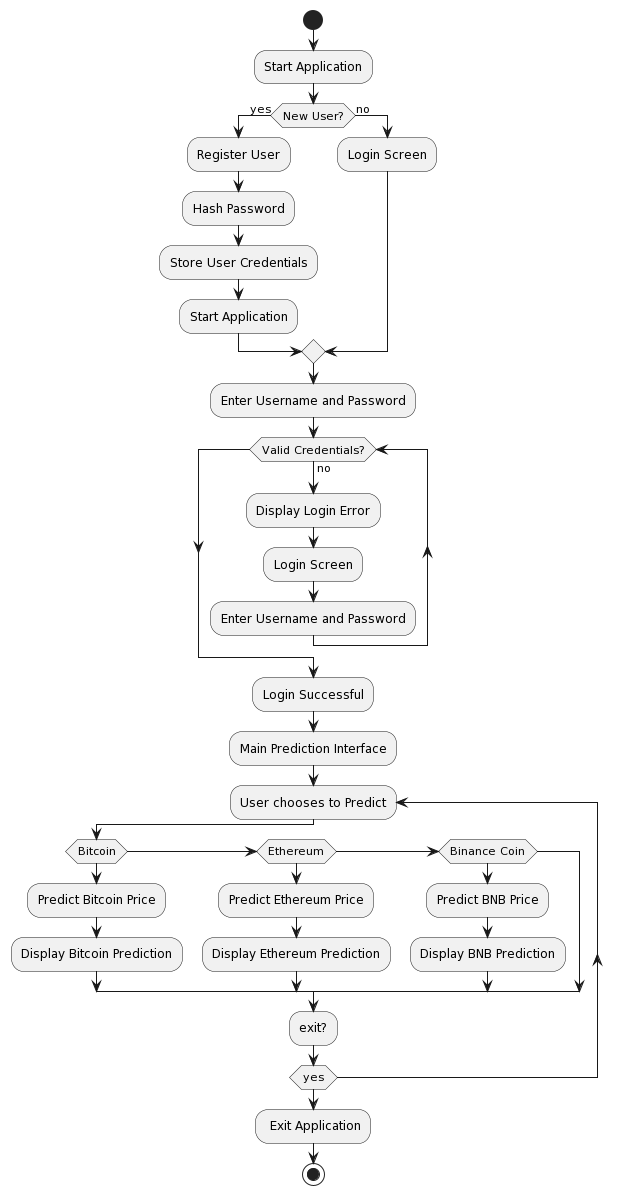
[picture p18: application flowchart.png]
Application Flow Chart
 
</p>

### Core Functionality

- **Hashing Passwords**: Utilizes the `hashlib` library to securely hash passwords with SHA-256.
- **Storing User Credentials**: Handles file operations to store and retrieve hashed user credentials.
- **User Authentication**: Includes functions to register new users, check for existing users, and authenticate user logins.
- **Cryptocurrency Price Prediction**: Integrates separate modules (`Bitcoin`, `ETH`, `BNB`) to predict cryptocurrency prices, showing the progress through a dedicated progress window.

### GUI Components

- **Registration Interface**: Allows new users to create an account.
- **Login Interface**: Enables existing users to log in using their credentials.
- **Main Prediction Interface**: Displays after successful login, providing options to predict prices of various cryptocurrencies.

### Multithreading

- Employs the `threading` module to run prediction tasks in separate threads, preventing the GUI from freezing during long-running operations.

### Progress Tracking

- Creates a progress window that informs users about the ongoing prediction task.
- Updates the main interface with the time taken for the last prediction once the task is complete.

### Entry Point

- The `main()` function initializes the Tkinter window, maximizes it, and calls the registration interface.

### Usage

#### Starting the Application
To launch the application, navigate to the directory containing the script and execute it. The registration window will appear, prompting new users to create an account.

#### Registering a New User
1. Click on the "Register" button on the main screen.
2. Enter a desired username and password.
3. Confirm the password by entering it again in the "Retype Password" field.
4. Click the "Register" button to create your account.
5. A message will confirm successful registration.

#### Logging in to the Application
1. From the main screen, click on the "Login" button.
2. Enter your username and password.
3. Click the "Login" button.
4. If the credentials are correct, a success message will appear, and you will be taken to the main prediction interface.

#### Predicting Cryptocurrency Prices
1. Once logged in, select the cryptocurrency for which you wish to predict the price.
2. Click the corresponding button, such as "Predict Bitcoin Price."
3. The application will begin processing and a progress bar will appear, indicating the prediction is underway.
4. Wait for the prediction process to complete. The time taken will be displayed at the bottom of the window once the process is finished.
5. Review the plotted prices displayed in the application.

#### Exiting the Application
To exit the application at any time, click the "Exit" button on any screen. This will close the application safely.

Note: All predictions are based on the most recent available data and use advanced machine learning algorithms to forecast future prices. However, the market can be volatile, and predictions should not be used as the sole basis for investment decisions.

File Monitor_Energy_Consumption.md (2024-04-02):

# Monitoring Energy Consumption and Efficiency

## 1. Setting Up lm_sensors

1. First, Install lm_sensors. For Ubuntu, execute:

```sh
sudo apt-get install lm-sensors
```
2. Configuration: Run the following command to detect and configure hardware sensors.
```sh
sudo sensors-detect
```

3. Usage: Use sensors command to check the available readings. Doing <b>sensors</b> command will display:

   

## 2. Integrating with Prometheus

To integrate hardware sensor data from tools like lm_sensors, with Prometheus for monitoring, a file is created which will translate data into a format Prometheus can scrape. Since Prometheus works by pulling metrics from HTTP endpoints, the goal is to expose the sensor data as HTTP endpoints.

### 2.1. Script to Expose lm_sensors Data

A script is written that outputs the sensor data in a Prometheus-friendly format ([See File Here](sensor_exporter.py)). 

### 2.2. Serve the Script Output Over HTTP
To make the data accessible to Prometheus, the script is served it over HTTP. The simple solution is to use Python's HTTP server functionality. [See here](http_sensor_exporter.py) basic wrapper script that serves exporter's output.

### 2.3. Configure Prometheus to Scrape the Custom Exporter

Add a new job to Prometheus configuration (prometheus.yml) to scrape this custom exporter:

```sh
scrape_configs:
  - job_name: 'sensors'
    static_configs:
      - targets: ['your_server_ip:8000']
```

###2.4. Restart
Restart HTTP server script and Prometheus to apply the changes.

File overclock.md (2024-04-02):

# Overclocking CPU via BIOS

Below are the steps that can be followed to overclock the CPU:

            Over Clock Using BIOS Configuration 

            Reboot your machine 

            Go to BIOS/UEFI using 'Del' or 'F2' Button  

After going inside BIOS, Navigate to Overclocking option, usually it is present in `Overclocking Settings` under `Advance` Settings.

            Navigate to Advanced

            Head to Overclocking CPU and Enable it

            Adjust CPU frequency 

When following these steps, it's important to note that the CPU frequency directly impacts the CPU's speed. Adjusting this parameter should be done cautiously, taking into account guidelines provided by the motherboard manufacturer. After modifying the frequency, it's essential to also adjust the voltage settings to ensure system stability. This involves carefully considering both the CPU speed and voltage, adhering to motherboard specifications throughout the process.

            Navigate to CPU Voltage

            Adjust them as required.

Once these steps are completed, press the "Esc" or "F10" key to exit the BIOS/UEFI setup utility. Save the changes made during the overclocking process before exiting. By following these steps, users can adjust the CPU frequency to suit their requirements.

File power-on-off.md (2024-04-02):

# **Power on and off function for HPC**
## **1. Implementation of power on and off function**

### **1.1 Background of Wake-On-LAN**
---
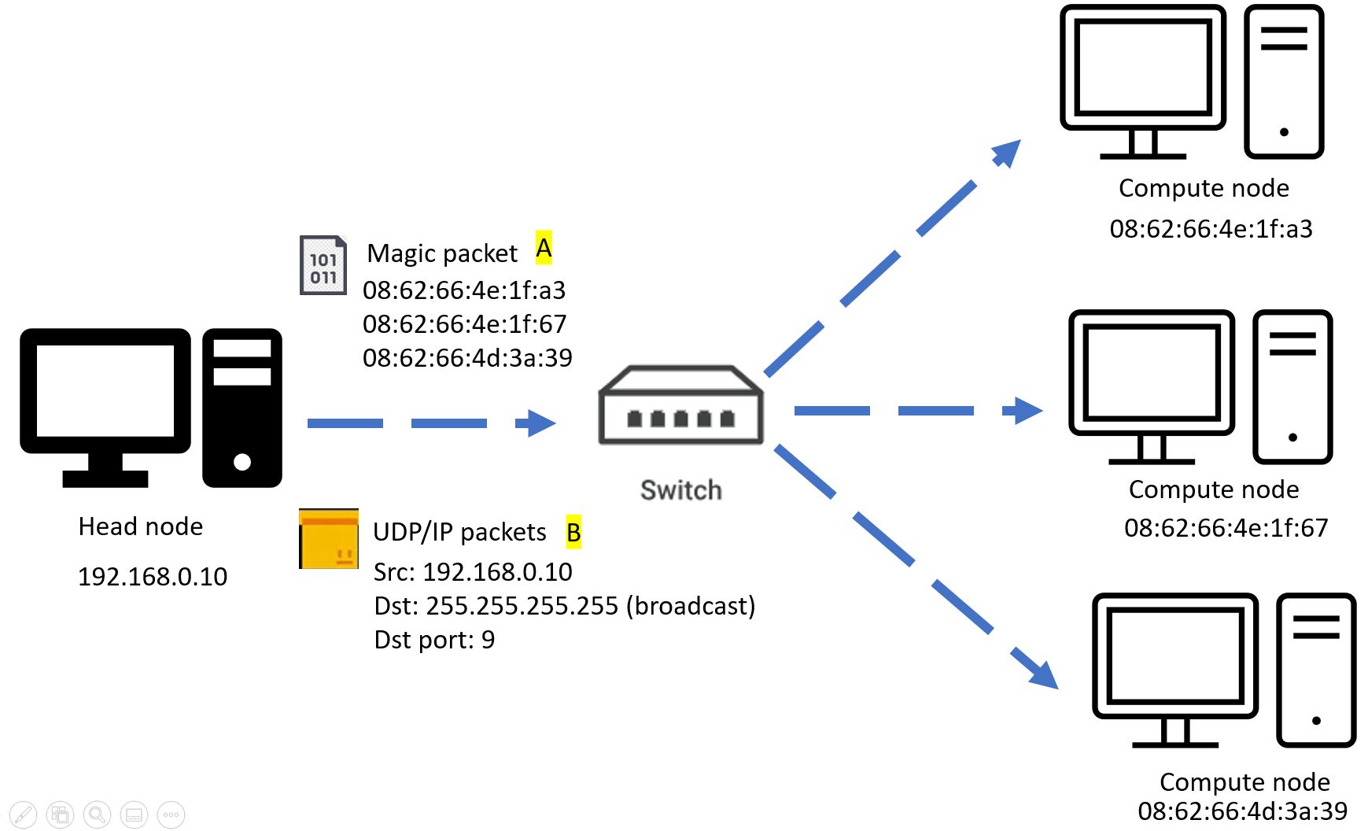
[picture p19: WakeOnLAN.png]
Wake On LAN info
<br>
<b>Figure 1: Wake On LAN working setup</b>
<br>

A network protocol known as Wake-On-LAN (WoL) enables a computer to be remotely powered on or awakened from a low-power state over a network connection. This technology allows for remote maintenance, updates and power control, making it very helpful for maintaining computer networks in places like offices and data centers. In this project, using Wake-On-LAN, a magic packet containing the etherwake command (instructing the compute nodes to turn on) along with the appropriate compute nodes' MAC addresses (connecting with the data bridge) will be sent. This enables the compute nodes to power on from the low-power state. A demonstration of it is shown in Figure 1.

As shown in Figure 1A, the magic packet will contain all the MAC addresses of the compute nodes in the network. Note, that all devices must be on the same network, which is 192.168.0.0, and have a valid NIC (Network Interface Card). Then, the magic packets will be broadcast in the network as shown in Figure 1B, which is 255.255.255.255. The magic packets will be sent to the relevant compute nodes by identifying each MAC address incorporated within the magic packets.

### **1.2 Setting up Power button on head node**
---

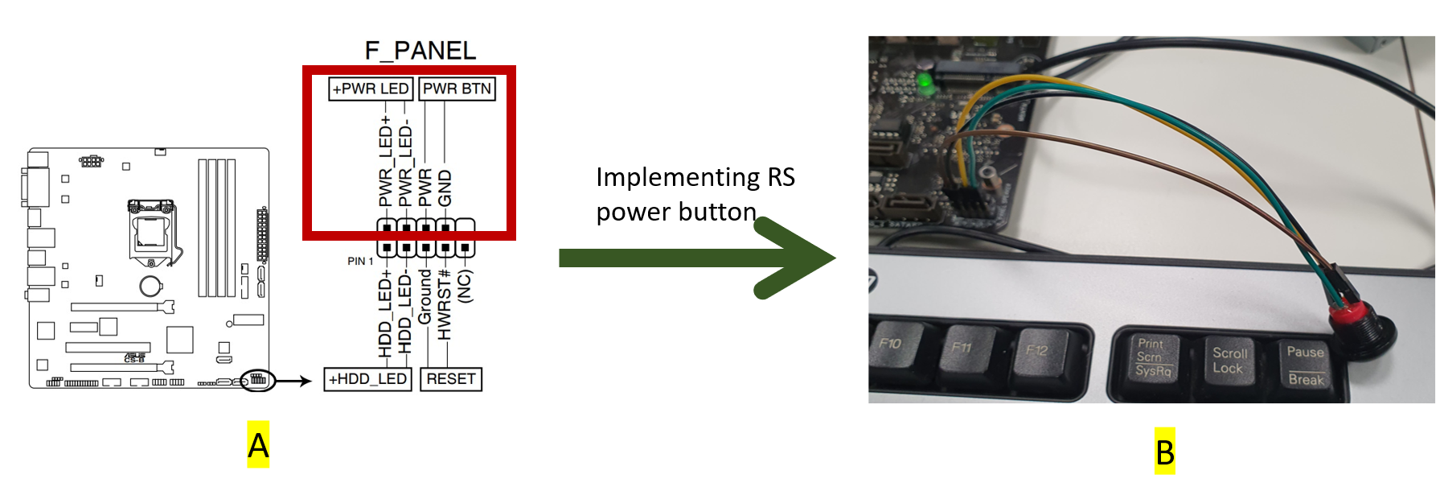
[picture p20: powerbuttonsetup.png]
Power button setup
<br>
<b>Figure 2: Implementing Power On and Off button on Head node motherboard</b>
<br>

As shown in Figure 2, must first identify the power button headers. As illustrated in part A, it was found that the front panel connectors are the connections to the power button and the power button's LED. Then, as shown in Figure 2 B, upon connecting the power button to the appropriate headers, the LED of the power button illuminates. After shutting down the system and turning it on using the power button, the head node successfully powers on. Furthermore, by pressing the power button after the head node is on, the head node displays a power-off option on the monitor. Through this process, the power on and off functionality was successfully implemented in the head node.

### **1.3 Setting up Wake-On-LAN magic packets communication**
---
<br>

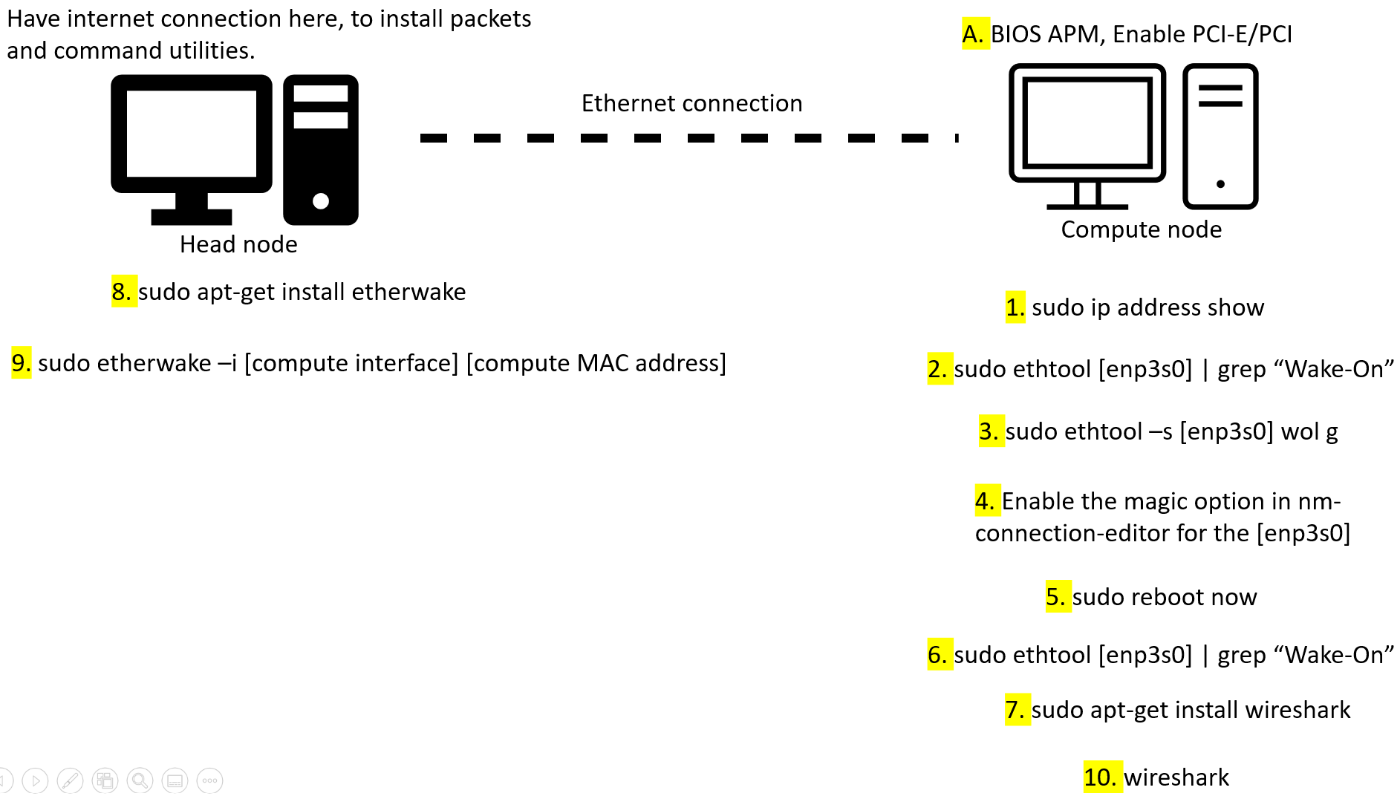
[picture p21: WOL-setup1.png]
Wake On LAN setup
<br>
<b>Figure 3: Implementing Wake-On-LAN between a head node and a compute node</b>
<br>

Following the letters and numbers on the above picture, below going to discuss the purpose of each line.

A. First, in the compute node BIOS, in the APM section related with power management, have to enable only the PCI-E/PCI, to enable Wake On LAN. It makes the compute node turn on when getting Wake on LAN magic packets only. Set the Restore AC Power LOSS to Power Off state.
1. To get the MAC address of compute node, which is a unique ID for the compute network interface.
2. To check the Wake-On-LAN state in the specific network interface. In initial, it will be d means disabled. Have to turn it on.
3. Here, making the Wake ON LAN activate by entering g at the end of the command.
4. However, after a reboot the WOL state will turn to d (disable). Therefore, have to make it persistent. In nm-connection-editor, by clicking magic, it will be persistent forever.
5. Reboot the compute node.
6. Verify whether the WOL is g or d state. It will be g, saying active state.
7. Install wireshark, which is a packet analyser. It will help to capture the incoming magic packets from compute node. Need only for testing purpose.
8. Install etherwake, to send Wake-On-LAN magic packets to compute node.
9. Sending a WOL magic packets to compute node, by specifying it’s network interface and MAC address.
10. Simultaneously, check whether the compute node receiving those packets by using wireshark GUI.
By following, the above steps successfully, can setup a Wake-On-LAN communication. 

### **1.4 Bash scripting for Wake-On-LAN**
---
After, setting up the WOL communication and Open-SSH, have to create a bash script to turn on and off the compute nodes, which performs after booting up of head node. This step took due to the failure of power on and off button process. 

    #! /usr/bin/env bash

    #define MAC address in array for etherwake function
    declare -a WakeUpMacs = (“08:62:66:49:4a:b7” “08:62:66:4e:1f:a3” “08:62:66:4e:1f:67” “08:62:66:4d:3a:e9”)

    #define ssh with IP address in array for power off function
    declare -a shutDownHosts = (“slave1@192.168.0.11” “slave2@192.168.0.12” “slave3@192.168.0.13” “slave4@192.168.0.14”)

    if  [“$1” = “-on”]; then
        #wake-up commands
        for mac in “${WakeUpMacs[@]}” ; do
            sudo etherwake -i enp3s0 “$mac”
        done
    elif [“$1” = “-off”]; then
        #shutdown commands
        for host in “${shutDownHosts[@]}”; do
            ssh “$host” ‘sudo shutdown now’
        done 
    else
        echo “Usage: $0 -on | -off” 
    fi

<b>Figure 4: Bash script to power on and off compute nodes</b>
<br>

As shown in Figure 4 above, a bash script was created to turn off and on the compute nodes. As illustrated in the bash script, the MAC addresses of the compute nodes and the SSH with IP addresses were stored in an array. Next, to turn on the compute nodes, the etherwake function was used within a for loop, and to turn off the compute nodes, sudo shutdown with appropriate SSH was used within a for loop. Finally, to detect any inappropriate input, an echo message was created to instruct on the correct input format.

## **2. Testing power on and off function**

After the successful implementation of Wake On LAN, 3 tests have been conducted:

### **2.1. Wireshark testing**
---

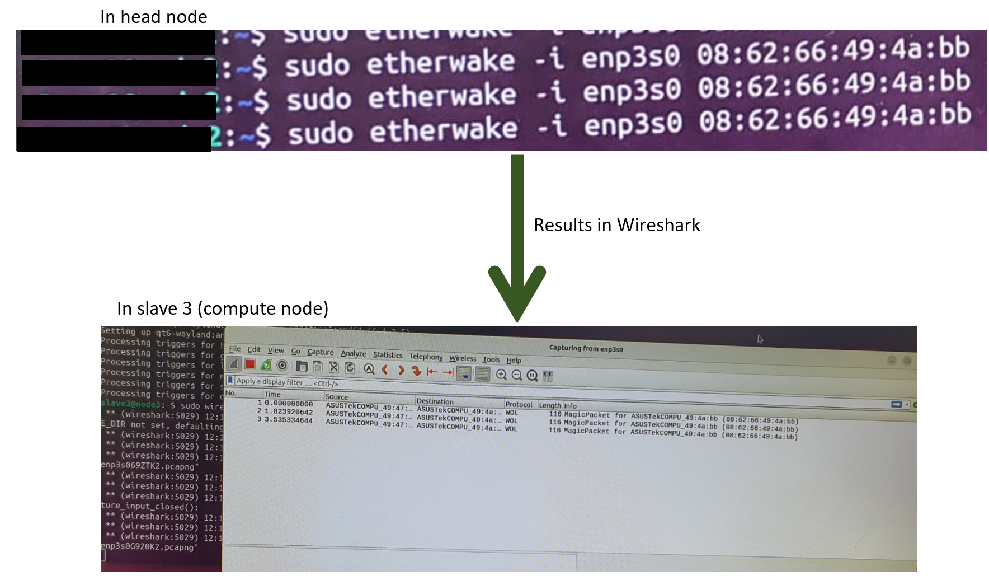
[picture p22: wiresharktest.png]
Wire shark testing
<br>
<b>Figure 5: Wireshark testing</b>
<br>
<ul>
<li>Purpose: To verify that WoL magic packets are correctly formatted and successfully transmitted over the network to wake up targeted devices from a low-power state.</li>

<li>Method: Network traffic is captured and analysed using Wireshark during the attempt to wake a device using WoL. This involves sending a magic packet containing the target device's MAC address over the network and monitoring for its transmission and receipt. (shown in Figure 5)</li>

<li>Results: As shown in Figure 5, the testing confirms the magic packet reaches the intended device and is properly constructed, indicating the built network configurations support WoL functionality. Similary, the above test has conducted across all compute nodes with head node. </li>
</ul>

### **2.2. Bash script power on testing**
---
<ul>
<li>Purpose: To verify whether the created bash script turns on the compute nodes from the head node.</li>

<li>Method: After the head node successfully boots up, the script name and the appropriate “-on” command have to be entered.</li>

<li>Results: As a result, the head node will not print anything in the terminal. The compute nodes start to turn on one by one as mentioned in the script's for loop.</li>
</ul>

### **2.3. Bash script power off testing**
---
<ul>
<li>Purpose: To verify whether the created bash script turns off the compute nodes.</li>

<li>Method: After successful power-on testing of the compute nodes, a power-off test is conducted. For that, similarly, enter the script’s name followed by the “-off” command.</li>

<li>Results: As a result, the head node will not print anything in the terminal. The compute nodes begin to turn off one by one as mentioned in the script's for loop.</li>
</ul>

 ## **3. Helpful Resources**

1. How to install WOL : https://pimylifeup.com/ubuntu-enable-wake-on-lan/#:~:text=Wake%2Don%2DLAN%20is%20a,functionality%20through%20your%20devices%20BIOS.
<br>

2. The button can be find here: https://uk.rs-online.com/web/p/push-button-switches/2099127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 gclid=EAIaIQobChMIpP3xg7-mhAMVFAUGAB0t5QD5EAQYByABEgIy1_D_BwE&gclsrc=aw.ds
<br>

3. Power button and Front panel connections : https://www.pcinq.com/how-to-connect-motherboard-front-panel-headers/ https://www.electronicshub.org/power-button-on-motherboard/#:~:text=Ans%3A%20The%20power%20switch%20on,for%20the%2020-pin%20header
<br>

 ## **5. Images**
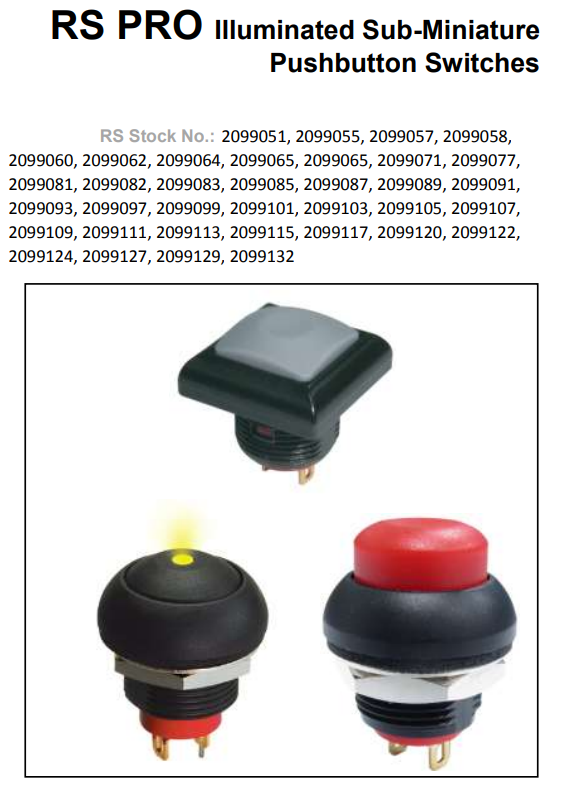
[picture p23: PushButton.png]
push button image
<br>
<b>Figure 6: Push button used in head node</b>
<br>

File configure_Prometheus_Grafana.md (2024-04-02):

## What is Prometheus 
•The primary uses of Prometheus, an open-source Linux server monitoring program, are alert management, event monitoring, and metrics monitoring.

•Because Prometheus has revolutionized system monitoring, the Cloud Native Computing Foundation (CNCF) has named it as one of its top projects.

•Prometheus supports dashboarding and graphing using a variety of modalities.

## Prometheus Components
The initial part of the Prometheus architecture is the Prometheus server. 
The central component of the Prometheus architecture, which is further split into storage, Prom, HTTP server, and so on, is the Prometheus server. 
Data is scraped from the target nodes in the Prometheus server and then saved in the database.

## Storage 
•The Prometheus server includes local on-disk storage . 

•Numerous interfaces in Prometheus enable integration with external storage systems.

## Service Discovery
•The services that need to be scraped are found with the use of service discovery.

•using the service discovery we can check what targets are activley being scraped aswell as monitoring all entitys 

## Scrape Target
•We can extract metrics and scrape metric from the target after the services have been determined and the targets are prepared.

•Node exporters allow us to export the endpoint's data.

•Prometheus keeps the metrics or other data in a local storage once it has been fetched.

 ## User Interface
Another crucial element is the user interface, which creates a link between the user and the system. Grafana, a visualization tool, and Prometheus work together to create excellent unique dashboards. Grafana dashboards show data using tables, pie charts, line charts, and data graphs of network load, CPU and RAM consumption, among other things, along with the ability to display alerts. Grafana uses prom ql in order to extract data from Prometheus

## What is Grafana
•Grafana, which is an open-source, free visualization tool that is typically utilized in conjunction with Prometheus to track metrics.

•Grafana offers a range of dashboards, diagrams, charts, and notifications for the specific data source.

•One of Grafana's key advantages is that we may share and store the dashboard with every member of the group. 

## Node exporter 
An agent called the Node Exporter collects system metrics and makes them available in a manner that Prometheus can read. One project that is managed by the Prometheus project is the Node Exporter. You can skip this step if system stats are not needed. We are using node exporter to scrape metrics from the different nodes and then relay them to Prometheus. The metrics scraped from port 9100 are for the head-node and the ports 9101,9102,9103 and 9104 are for the sub-nodes 

# Steps taken to configure both Prometheus 

## Creating Prometheus System Users and Directory
In this section I configured the system user, created directories where the configuration files will be stored and set the ownership of the Prometheus directory 

*sudo useradd --no-create-home --shell /bin/false Prometheus* -- Create a system user for Prometheus

*sudo mkdir /etc/prometheus*

*sudo mkdir /var/lib/Prometheus – stores the libraries and configuration files of the directories*

*sudo chown prometheus:prometheus /var/lib/prometheus -- sets prometheus as the owner of the directory*

## Download Prometheus Binary File
In this section I downloaded the latest version of prometheus for our operating system from the prometheus home page under downloads 

*cd /tmp/--enters tmp*

*wget. https://github.com/prometheus/prometheus/releases/download/v2.46.0/prometheus-2.46.0.linux-amd64.tar.gz –uses wget command to download the prometheus setup 
tar -xvf prometheus-2.46.0.linux-amd64.tar.gz – extracts the file form the setup*

## moves config file and sets the user access 
 *cd prometheus-2.46.0. linux-amd64* –- enters the Prometheus download
 
 *sudo mv console* /etc/prometheus* –- moves the configuration file
 
 *sudo mv prometheus.yml /etc/prometheus* –- moves the configuration file
 
 *sudo chown -R prometheus: prometheus /etc/prometheus* –- sets the user of prometheus

## Prometheus configuration file
In this section I confirmed the Prometheus yml file was present and modified as needed. i set the evaluation time and scrape intrval time to 15 seconds then
I added all data points that I wanted to scrap in the scrap configs section with the main prometheus job in the scrape config section. An alert manager can also be implemented if necessary to alert the user of certain readings that exceeds recommeneded values   
prometheus
<b>Figure .1 shows the prometheus yml file   </b>
<br><br>

## Creating Prometheus Systemd file
In this section I created a service file that sets up its startup and states its service type and users. I then reloaded the system to confirm the setup. The code used will be included in the appendix. 
system MD-Prom
<b>Figure .2 system.MD file for prometheuese   </b>
<br><br>

 *./prometheus –config.file=prometheus.yml (or) ./prometheus – launches the Prometheus server*  
 
## Verification 
As the default configuration for the prometheus the local host on port 9090 we can verify that its up by accessing http://server-ip-address:9090.on our web browser. When the prometheus interface was displayed I could see if was configure correctly 

## Installing Grafana
Grafana was then installed by following a similar process which was adding the Grafana repository to the system and then installing it and updating the packages by using the *get-update* and *apt-get* commands. Followed by enabling the server using the enable command. The password for Grafana was then changed to using the *sudo grafana-cli admin reset-admin-password* command 

## Prometheus and Grafana inter-connection 
I added the prometheus connection my adding the URL of prometheus local host 9090 as a new data source and then saving the configuration. From here I created a new dashboard using the data source based of a template on the grafana download page 

## Grafana graphs 
The first graph displays the CPU core usage which tells us the percent of processing power that is being used as well as the memory usage which show the amount of ram being utilized 

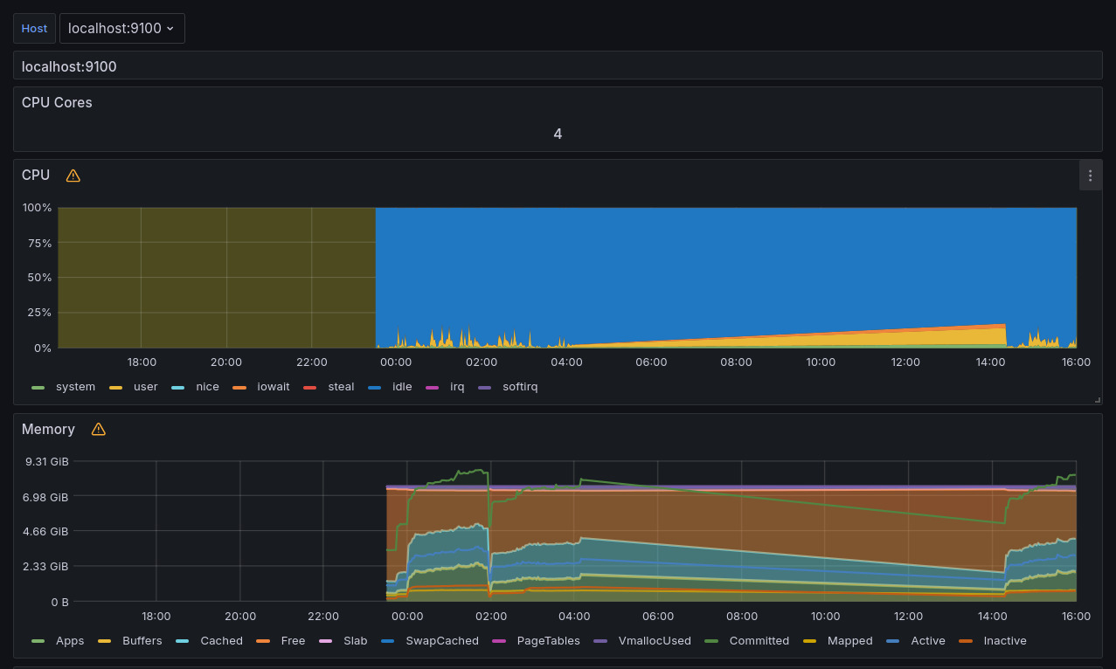
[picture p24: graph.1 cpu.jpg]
<br>
<b>Figure .2 cpu and memory graph readings </b>
<br><br>

The second graph used displayed disk space which determines the total data the hard disks can store. It also displays the load carried by the board

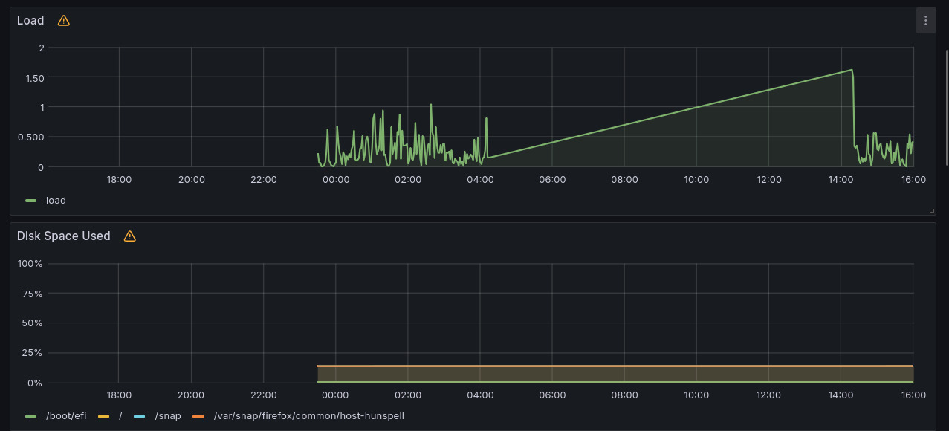
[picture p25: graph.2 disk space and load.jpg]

<b>Figure .3 load and the disk usage readings  </b>
<br><br>

The third graph shows the disc utilization per device which is the percentage of your hard disk your computer is currently using to run programs and carry out tasks. It also displays the rate the disc can read or write to a device 

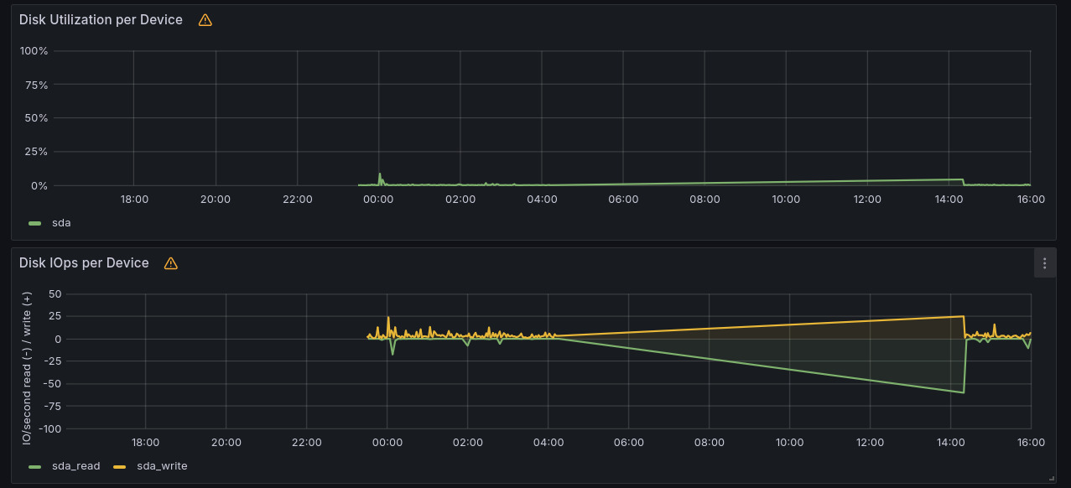
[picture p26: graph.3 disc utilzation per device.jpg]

<b>Figure .4 disk usage per device and sta/stw readings   </b>
<br><br>

The fourth and final graph displays context switches which are the process of switching the CPU from one process, task or thread to another. It also shows the traffic over the network 

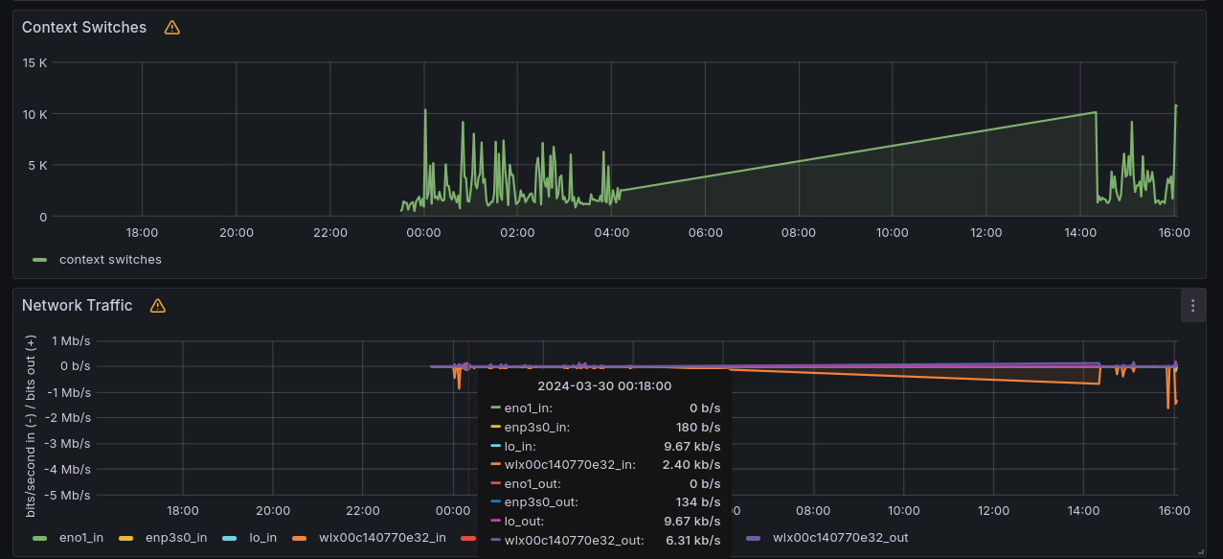
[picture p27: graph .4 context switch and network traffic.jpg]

<b>Figure .5 context switch and network readings   </b>
<br><br>

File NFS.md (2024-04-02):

# Configuring NFS In Head Node

This file outlines the steps to configure NFS in a Network.

## Prerequisites
All the nodes must be ina same network and should be able to ping each other. It is suggested to configure Open SSH aswell. 

1. Install nfs-server in the head node.
      
         sudo apt update
         sudo apt-get install nfs-server

2. Establish a shared directory on the head node and modify the '/etc/exports' file to grant permission to all client nodes to access the '/nfs' directory.  

         mkdir /nfs
         sudo nano /etc/exports
         # add the following line inside /etc/exports
         /nfs *(rw,sync)

3. Restart nfs-kernel-server
         
         sudo systemctl nfs-kernel-server restart

4. Changing the ownership of '/nfs' from root to user

         sudo chown #username /nfs

5. Check the ownership of the file to be sure

         ls -ld /nfs

### Configuring NFS In Client Node

1. Install nfs-client in the client node 

         sudo apt update
         sudo apt-get install nfs-client

2. Create a similar shared directory '/nfs' as headnode

         mkdir /nfs 

3. Navigate to the '/etc/fstab' file and add the file system to be mounted on the client node.
   
         sudo nano /etc/fstab
         #add the following line to mount /nfs 
         headnode_username:/nfs /nfs nfs

      #### NOTE: if you get an error while unmounting the file in client node, you can use ip-address of headnode instead of username 

4. Restart daemon if necessary 

         sudo systemctl daemon-reload

5. Mount all file partitions.

         sudo mount -a

After following the steps provided above, users will be able to configure NFS on their cluster computers. After configuring NFS, the resource management system should be set up to handle processes.

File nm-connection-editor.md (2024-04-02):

# **Networking with nm-connection-editor**

## **1. Background of nm-connection-editor**

The nm-connection-editor helps to create new network connections and manage existing network connections in Linux OS. It is a GUI based application.

                sudo nm-connection-editor

By typing the above command in Linux terminal, user can start the nm connection editor application. It is only available in GUI (desktop or GNOME) environment. To instead work with terminal, can use nm-cli connection. It available in all platforms such as terminal, desktop and ssh,or instead, can use nmtui, it is a curses-based application. It works on terminal and desktop and support all the feature of network manager.

<b>Table 1: Comparing nmtui and nm-connection-editor</b>
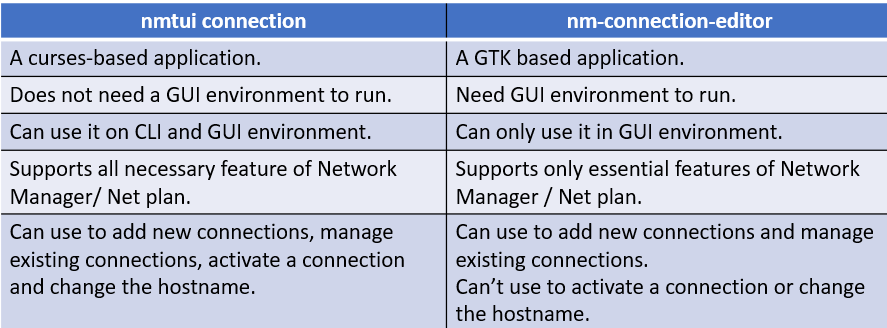
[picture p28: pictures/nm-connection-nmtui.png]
nmtui_nmconnections
<br>
<br><br>

## **2. Methodology of nm-connection-editor implementation**
 
### **2.1 How to add a new network connection with nm-connection-editor**
<br>

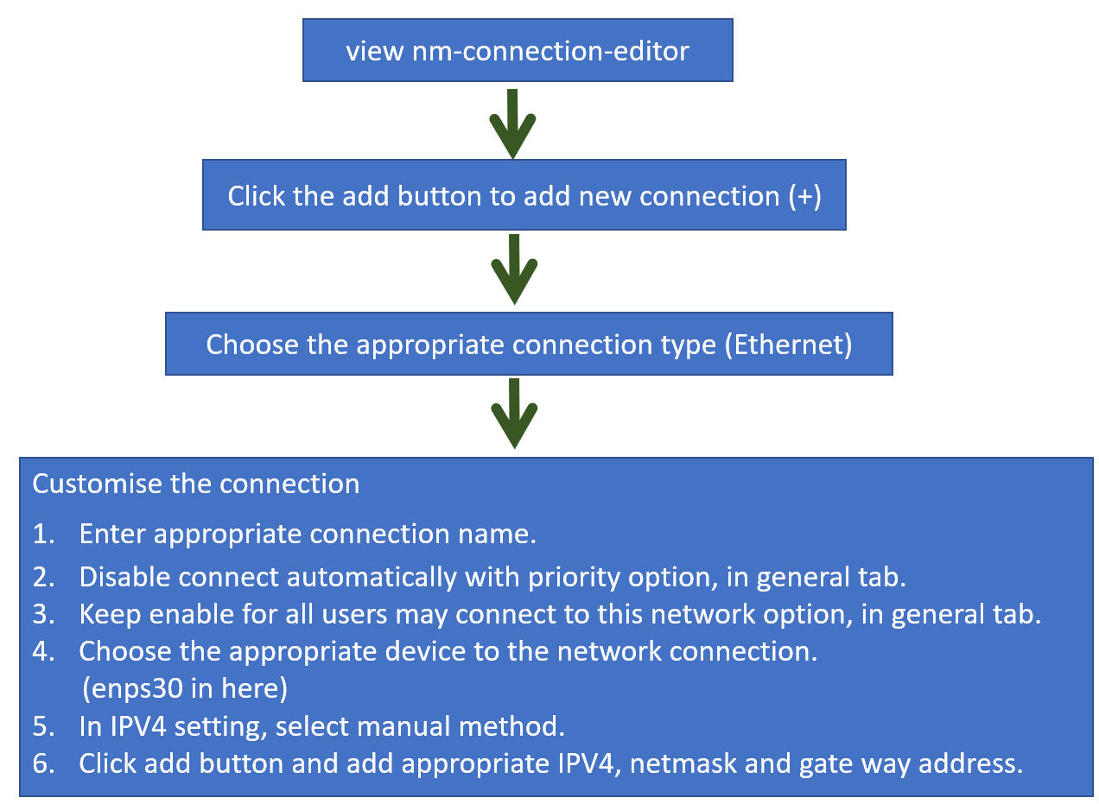
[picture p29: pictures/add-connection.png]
new_nm_connections
<br>
<b>Figure 1:Flow diagram to add a new network connection in nm-connection-editor</b>
<br><br>

(Note: The above flow chart, made in consideration of following static IP address configuration and HPC purpose only.)

In the head node, the nm-connection editor saves all the network configuration files in etc/sysconfig/network-scripts/ directory.

                    sudo nmcli connection show

By using the above command, can verify the made network connections.

                    sudo nmcli connection up [Network Connection name]
By using the above command, can activate the specific network connection.

                    sudo ip address show [Network interface]

After activating network connection, can view the IP configuration of the specific device.
<br>

### **2.2 How to edit a network connection with nm-connection-editor**

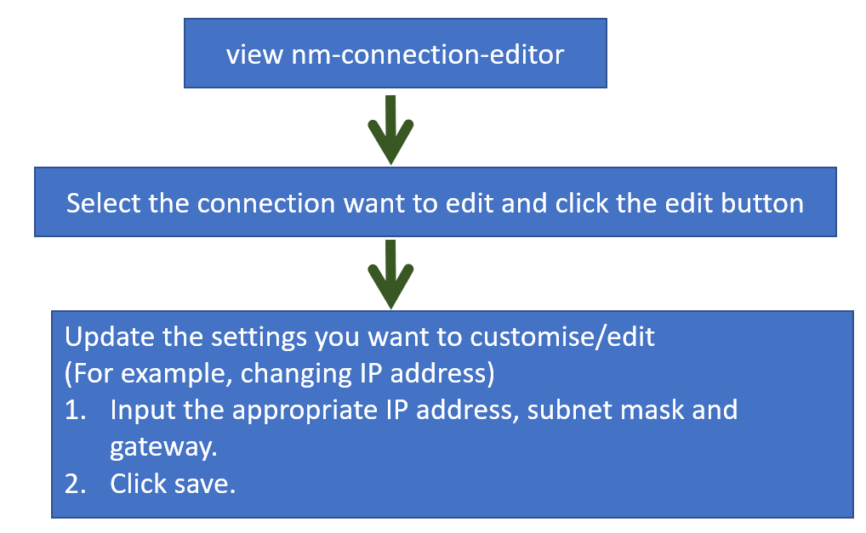
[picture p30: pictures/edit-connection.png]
edit_nm_connections
<br>
<b>Figure 2:Flow diagram to edit network connection in nm-connection-editor</b>
<br><br>

                    sudo nmcli connection down [Network Connection name]
		            sudo nmcli connection up [Network Connection name]
After customisation, the Network Manager/ Net plan won’t change the customise options. Therefore, must manually change the customisation by shutting down and turning on network connection.

                    sudo ip address show [Network Interface]
Verify the customised  IP address changed/ updated.
<br>

 ### **2.3 How to delete a network connection with nm-connection-editor**

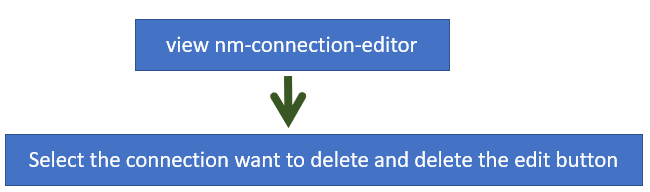
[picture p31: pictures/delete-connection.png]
delete_nm_connections
<br>
<b>Figure 3:Flow diagram to delete a network connection in nm-connection-editor</b>
<br><br>

                    sudo nmcli connection show 
Can verify the connection above was deleted.
<br>

## **3. Networking implemenatation for HPC**

### **3.1 Network bridging**

To implement networking for this project, have used the network bridging format. It has been enabled with two ethernet cables, as follows:
<ol>
<b><li> Internet Sharing Cable</li></b>
<ul>
<li>	Purpose: Used to provide internet access to all network devices in the HPC. </li>

<li>	How it Functions: The HPC's head node has an internet connection through the Wi-Fi adapter, but the other compute nodes do not. Therefore, to share the internet connection with the other compute nodes, this internet sharing cable was established.</li>

<li>	Assigned Port (NIC) Name: en01</li>
</ul>
<b><li> Data Sending Cable</li></b><ul>
<li>Purpose: Used to share data packets or facilitate intra-communication between the nodes in the HPC.</li>

<li>How it Functions: In the HPC, most of the function inputs and packet installations occur in the head node. However, to enable parallel processing, the installed packets have to be present in both the compute node and the head node. Furthermore, the head node must send inputs or tasks to the compute nodes to perform. Therefore, an intra-communication link is needed. To fulfill this purpose, these data sending cables were established on all nodes’ NICs.</li>

<li>Assigned Port (NIC) Name: enp3s0 </li>
</ol>

### **3.2 Static IP Address**

After establishing network connections, it is necessary to assign an IP address to each node to uniquely identify each one in the HPC network. Therefore, we use static IP address configuration. A static IP address means manually assigning an IP address to network devices. In this case, a Class C IPv4 address is used. The given subnet mask is /24 or 255.255.255.0.The assigned IP addresses are shown below in Table 2. Additionally, the table contains the MAC address of each node.

<b>Table 2: IP Address and MAC Address of each node</b>
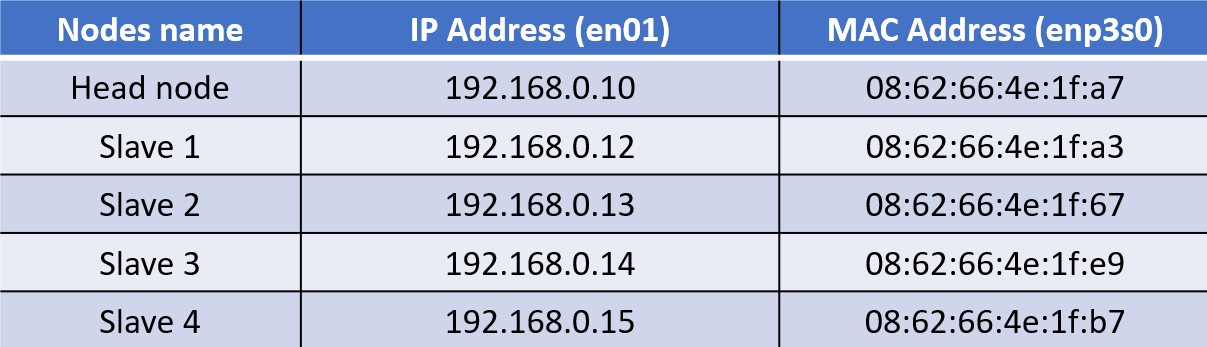
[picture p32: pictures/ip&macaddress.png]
ipandmacaddressinfo
<br>
<br>

### **3.3 Network implementation in HPC using nm-connection editor**

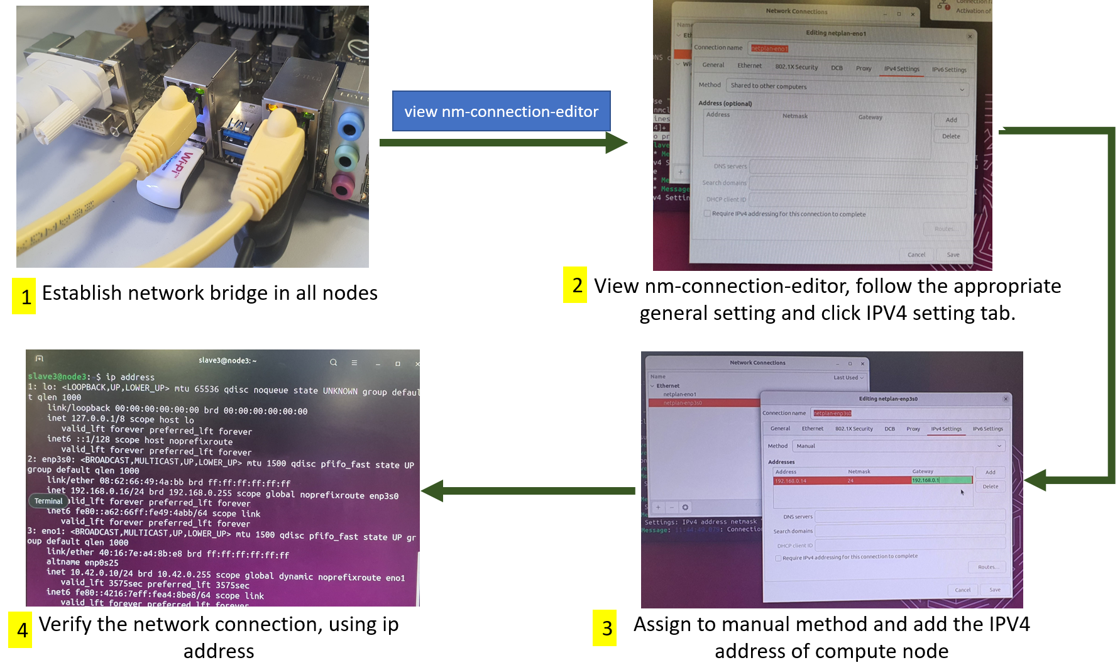
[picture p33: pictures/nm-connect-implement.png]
nm-connect-implement
<br>
<b>Figure 4:Implementation of networking in HPC using nm-connection-editor</b>
<br>

In accordance with the methodology described in section 2.1, a static IP address was assigned to each node, as detailed in Table 2. Figure 4 illustrates the implementation of this setup. As depicted in Figure 4, this implementation was applied to each node to manage the network within the HPC.

### **3.4 Implemented network topology**

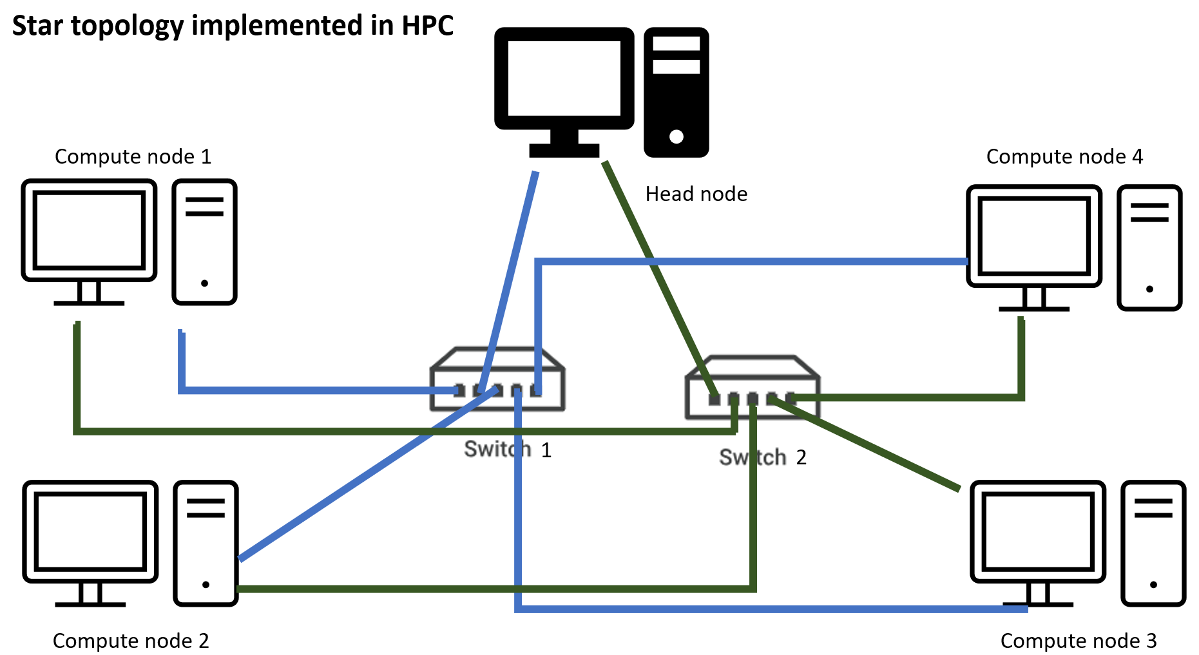
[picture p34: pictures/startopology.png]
topology-implement
<br>
<b>Figure 5: Network topology implemented in HPC</b>
<br>

For this HPC’s network, star network topology has been implemented, as shown in Figure 5. In a star topology, each node is independently connected to a central hub or switch. If one node fails, it does not affect the rest of the network, as each has a direct line to the switch, which facilitates error detection and isolation. This topology is common in Ethernet LANs because of its simplicity and the ease with which systems can be added or removed. In the above can observe two topologies, due to internet sharing and data sharing ethernet connection.

## **4. Testing networking implementation**
### **4.1 Verification of Internet Connection**

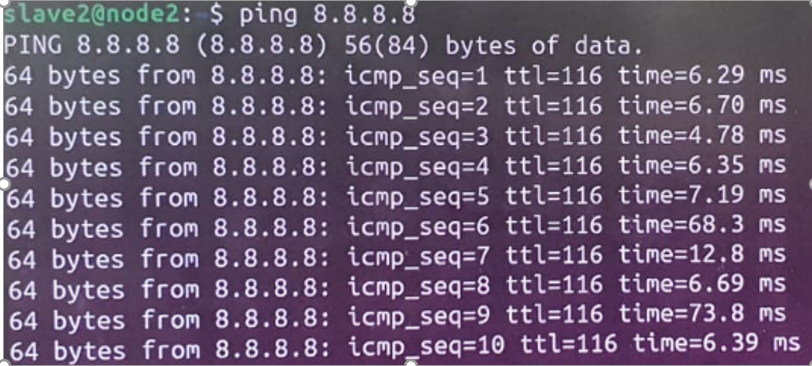
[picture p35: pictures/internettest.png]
internet_test
<br>
<b>Figure 6: Internet connection test on compute node</b>
<br>

<ul>
<li>Purpose: To confirm that an internet connection is shared among all nodes.</li>

<li>Method: This is achieved by pinging Google's DNS (Domain Name System) server, as depicted in Figure 6.</li>

<li>Result: As shown in Figure 6, executing the command ping 8.8.8.8 on one of the compute nodes—which targets Google’s DNS Server—successfully verifies that the internet connection is active on that node. This procedure was replicated across all nodes, with each reporting successful outcomes. Therefore, it can be concluded that downloading necessary packages on the compute nodes is feasible, indicating a functioning internet connection across the network.</li>
</ul>

### **4.2. Ping Tests**

ping_test<br>
<b>Figure 7: Ping test on compute node</b>
<br>

<ul>
<li>Purpose: To verify basic connectivity between nodes and measure the round-trip time (RTT) for packets.</li>

<li>Method: The method involves using the ping command to send ICMP (Internet Control Message Protocol) echo requests to each node, as illustrated in Figure 7.</li>

<li>Result: As depicted in Figure 7, on one of the compute nodes, executing the command ping 192.168.0.10 targets the head node's IP address and successfully completes the ping test. This test was similarly conducted across all nodes, yielding successful outcomes. This demonstrates that connectivity between nodes is established, allowing for effective communication and coordination within the network.</li>
</ul>

 ## **5. Helpful Resources**
 1. How to implement nm-connection editor: https://help.ubuntu.com/community/NetworkManager

2. Star topology information: https://www.techtarget.com/searchnetworking/definition/star-network

3. Network bridge implementation information: https://www.howtogeek.com/892923/what-is-a-network-bridge-and-should-you-use-one/

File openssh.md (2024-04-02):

# Open-SSH Server Configuration
This file contains step by step guide to configure OpenSSH server in a ubuntu environment.

## Prerequisites:
Ensure that Ethernet connections are properly established across all nodes and that all ports are correctly configured.

## STEP 1: Installing Open-ssh Server in Head Node
Initially, input the command below to update all repositories in the Linux operating system.

                    sudo apt update

Next, execute the "install openssh-server" command to install all the required components. Respond with `yes` to all system prompts to ensure the successful installation of OpenSSH.

                    sudo apt install openssh-server

In most cases, the SSH server is already enabled. However, to confirm, enable the SSH service:

                    sudo systemctl enable ssh

Then, using the command provided below, verify the status of openSSH server. It will show if the ssh is active and loaded.

                    sudo systemctl status ssh     

Finally, SSH traffic should be allowed in the firewall and following command can be used to allow incomming SSH connection:

                    sudo ufw allow ssh

## STEP 2: Installing Open-ssh Server in Compute Nodes
The same steps used for configuring the OpenSSH server on the head node can be replicated on all compute nodes.

## STEP 3: Accessing compute nodes using Open-SSH connection

access SSH<br>
<b>Figure 1: Viewing the compute node from head node, using SSH</b>
<br><br>

## Step 4 : Setting up Passwordless SSH Login System

To establish a passwordless login system, begin by generating an SSH key pair on the head node using the command:

        ssh-keygen -t rsa 

Press `enter` to all the system prompts, which will generate the SSH key pair inside the .ssh directory in the home directory. Two keys will be created: 'id_rsa' and 'id_rsa.pub'.

The public key, denoted by `.pub`, must be copied to all other compute nodes using the following command:

        ssh-copy-id compute_node_username@ip_address

Once this step is completed, the passwordless login system will be established.

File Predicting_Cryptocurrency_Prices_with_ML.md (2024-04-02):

# Creatting Machine Learning for predict cryptocurrency
Machine learning constitutes a complex task; therefore, to facilitate an easier understanding of the process, the following flowchart is provided. This demonstration utilises Bitcoin as an example, yet the application maintains the same structure for each cryptocurrency.

<p align="center">
  Machine Learning Flow Chart
</p>

## Libraries and Modules Documentation

### Core Python Libraries

- **`array`**: Provides space-efficient storage of basic C-style data types. Used for specific low-level data operations.
- **`math`**: Essential for advanced mathematical operations, such as square roots or logarithms, beyond basic arithmetic.

### Data Manipulation and Analysis

- **`pandas`** (`pd`): A pivotal library for data manipulation and analysis, ideal for working with structured data.
- **`numpy`** (`np`): The foundational package for numerical computing in Python, supporting array operations, mathematical functions, and more.

### Machine Learning and Neural Networks

- **`sklearn.preprocessing.MinMaxScaler`**: Scales features to a specified range, usually between zero and one, crucial for many machine learning algorithms.
- **`keras.models.Sequential`**: Allows for easy assembly of models where each layer has exactly one input tensor and one output tensor.
- **`keras.layers`**: Contains various neural network layers, including:
  - **`Dense`**: Standard fully connected neural network layer.
  - **`LSTM`** (Long Short-Term Memory): A type of RNN layer important for sequence prediction problems.
  - **`GRU`** (Gated Recurrent Unit): A streamlined version of LSTM, faster to train but similarly effective for sequence data.

### Data Visualization

- **`matplotlib.pyplot`** (`plt`): A comprehensive library for creating static, animated, and interactive visualizations in Python.

### Financial Data

- **`yfinance`** (`yf`): Enables access to Yahoo Finance's market data, useful for obtaining historical financial data for analysis.

### Date and Time Management

- **`datetime`**: Provides classes for manipulating dates and times, crucial for managing time series data effectively.

### Performance Metrics

- **`sklearn.metrics`**: Includes various metrics for evaluating the performance of machine learning models, such as:
  - **`mean_squared_error, mean_absolute_error`**: Quantify the average errors between predicted and actual values.
  - **`explained_variance_score, r2_score`**: Assess the explanatory power of regression models.
  - **`mean_poisson_deviance, mean_gamma_deviance`**: Evaluate models for count 

These libraries collectively support the processes of data preparation, modeling, evaluation, and visualization for this ML.

```bash 

# -*- coding: cp1252 -*-
from array import array
from pickletools import optimize
import math
from sklearn.metrics import mean_squared_error, mean_absolute_error, explained_variance_score, r2_score 
from sklearn.metrics import mean_poisson_deviance, mean_gamma_deviance
from statistics import mode
import matplotlib.pyplot as plt
import pandas as pd
import numpy as np
from sklearn.preprocessing import MinMaxScaler
from keras.models import Sequential
from keras.layers import Dense, LSTM, GRU
import yfinance as yf
from datetime import datetime, timedelta

```
## Getting Data
The initial step in creating a Machine Learning model involves accessing historical data for the cryptocurrencies that will be utilised for making predictions. Initially, the use of an API to access this historical data was contemplated. However, due to the constraints imposed by APIs, the decision was ultimately made to employ data available from Yahoo Finance. This platform facilitates the acquisition of historical datasets for the most significant cryptocurrencies. For this project, data pertaining to Bitcoin, Ethereum, BNB will be used.

The following code retrieves historical price data for Bitcoin (BTC) against the US Dollar (USD) for analysis and prediction purposes:

- **`ticker_symbol`**: Specifies the financial instrument of interest, in this case, "BTC-USD", representing Bitcoin priced in US Dollars.
- **`start_date`**: Defines the start date for the historical data fetch. Here, it's set to "2014-09-17", marking the beginning of the period for which data is requested.
- **`end_date`**: Determines the end date of the data retrieval period. This is dynamically set to the date of the day before the script runs, ensuring the dataset includes the most recent complete day of trading data available.

``` bash
        ticker_symbol = "BTC-USD"
        start_date = "2014-09-17"
        end_date = self.get_yesterday_date()

        # Fetch historical data
        self.BTC_data = yf.download(ticker_symbol, start=start_date, end=end_date)
```        

## Processing the data
To process the data, the pandas library is being utilised, which will enable us to manipulate the data as desired.

``` bash
self.BTC_data= pd.read_csv(file_path,index_col='Date', parse_dates=['Date'], dayfirst=True)
```
`pd.read_csv()`: This function is pandas' workhorse for loading CSV files. It's versatile and powerful, allowing for fine-tuning of the data ingestion process.
`pd.read_csv()`: This function is pandas' workhorse for loading CSV files. It's versatile and powerful, allowing for fine-tuning of the data ingestion process.

`index_col='Date'`: By setting the Date column as the index, you transform the dates into the DataFrame's row labels, making time-series data manipulation more intuitive.
`index_col='Date'`: By setting the Date column as the index, you transform the dates into the DataFrame's row labels, making time-series data manipulation more intuitive.

`parse_dates=['Date']`: This ensures the 'Date' column is treated as datetime objects, not strings, unlocking time-sensitive methods and functionality.
`parse_dates=['Date']`: This ensures the 'Date' column is treated as datetime objects, not strings, unlocking time-sensitive methods and functionality.

`dayfirst=True`: This parameter is crucial for correctly interpreting dates when the day precedes the month in your data source, avoiding common pitfalls in date parsing.
`dayfirst=True`: This parameter is crucial for correctly interpreting dates when the day precedes the month in your data source, avoiding common pitfalls in date parsing.

In order to facilitate predictions based on the Bitcoin dataset, parameters such as the high price and volume will be selected. However, since these may not be sufficient for accurate forecasting, technical indicators will also be incorporated to enhance the predictive capability.

## Technincal Indicators
The technical indicators RSI, EMA and SMA are generally used for financial analysis to understand market dynamics and generate trading signals. Those indicators will help ML model to identify complex patterns

### Simple Moving Average (SMA)
 The average price of a security or asset over a given length of time, it is determined by summing up the prices for a given number of periods and dividing those values by the same number of periods. Can assist in identifying both 11 short-term and long-term trends in the data

$$
\text{SMA} = \frac{\sum_{i=1}^{N} P_i}{N}
$$

  Where:

  - $N$ is the number of periods used in the calculation.
  -  $P$<sub>i</sub> denotes the price of the asset at period $i$.

### The Exponential Moving Average (EMA) 
IT is a type of moving average that places a greater weight and significance on the most recent data points. It is also referred to as the exponentially weighted moving average. EMAs are commonly used to gauge the direction of the trend in the prices of financial assets such as stocks or cryptocurrencies.

$$
EMA_t = (V_t \times \left(\frac{s}{1+d}\right)) + EMA_{t-1} \times \left(1 - \frac{s}{1+d}\right)
$$

Where:

- \(EMA_t\) is the EMA today.
- \(V_t\) is the value today.
- \(s\) is the smoothing factor, typically 2.
- \(d\) is the number of days.
- \(EMA_{t-1}\) is the EMA of the previous day.

In simpler terms:

$$
\text{EMA} = \text{Current Price} \times \text{Smoothing Factor} + \text{EMA}_{\text{previous day}} \times (1 - \text{Smoothing Factor})
$$

EMA involves two main components: the smoothing factor and the previous EMA value. The smoothing factor determines the weightage given to the most recent data point and is typically derived from a specified time period or the number of data points. Since it places more emphasis on recent data, the EMA reacts more quickly to price changes compared to the SMA.

### The Relative Strength Index (RSI)
RSI a momentum oscillator that measures the speed and change of price movements. The RSI oscillates between zero and 100 and is typically used to identify overbought or oversold conditions in trading assets, indicating a potential reversal in price.

The RSI is calculated using the following formula:

$$
\text{RSI} = 100 - \frac{100}{1 + \text{RS}}
$$

Where RS (Relative Strength) is the average gain of the up periods divided by the average loss of the down periods over the specified time frame.

$$
\text{RS} = \frac{\text{Average Gain over N periods}}{\text{Average Loss over N periods}}
$$

### Intregation of technical indicators 
To add those indiciators  to our dataset will be use function that will make all the calculations required and added to our orginal data set.

```bash
 def technical_indicators(self,dataset):

            # Create Exponential moving average
               dataset['ema'] = dataset['Price'].ewm(com=0.5).mean()

            # Calculate RSI
            delta = dataset['Price'].diff(1)
            gain = (delta.where(delta > 0, 0)).rolling(window=14).mean()
            loss = (-delta.where(delta < 0, 0)).rolling(window=14).mean()

            RS = gain / loss
            RSI = 100 - (100 / (1 + RS))

            dataset['RSI'] = RSI

            # Calculate SMA (Simple Moving Average)
               dataset['SMA30'] = dataset['Price'].rolling(window=30).mean()  # 30-day SMA
               dataset['SMA21'] = dataset['Price'].rolling(window=21).mean()  # 21-day SMA, if needed

            return dataset

```
After integreating the all technical indicators the next step will be to scale and split the data.

## Scalign and Splitting
### Scaling features
First, the feautes price, volumen and all the previus technical  are extracted form the DataFrame and then, scaled independently using the MinMaxScaler from the scikit-learn library. This scaler transforms each feature by scaling it to a given range, here defaulting to [0, 1], which is the typical range for MinMaxScaler without specifying any arguments. This normalization step is crucial for neural network models to converge more quickly and efficiently during training.

```bash

    # Separate the features
   prices = self.BTC_data[['Price']].values
   volumes = self.BTC_data[['Volume'].values
   EMA = self.BTC_data[['ema']].values
   SMA= self.BTC_data[['SMA30']].values
   RSI=self.BTC_data[['RSI']].values

   # Scale each feature independently
   scaler_price = MinMaxScaler()
   scaler_volume = MinMaxScaler()
   scaler_EMA = MinMaxScaler()
   scaler_SMA= MinMaxScaler()
   scaler_RSI= MinMaxScaler()

   prices_scaled = scaler_price.fit_transform(prices)
   volumes_scaled = scaler_volume.fit_transform(volumes)
   EMA_scaled = scaler_EMA.fit_transform(EMA)
   SMA_scaled = scaler_SMA.fit_transform(SMA)
   RSI_scaled= scaler_RSI.fit_transform(RSI)

```

After scaling, all features are concatenated horizontally (axis=1) to form a single array, scaled_features, where each row represents a timestamp, and each column represents a scaled feature.

```bash
# Concatenate the scaled features
caled_features = np.concatenate([prices_scaled, volumes_scaled, EMA_scaled,SMA_scaled,RSI_scaled], axis=1)
```

### Spliting the Dataset
#### Setting Parameters
Now is required to prepare the scaled features for training, validation, and testing by splitting the dataset according to specified ratios.
For that task it is goin to set:
- `time_step`: This parameter specifies the window size for each input sequence to the model. In this context, a time_step of 30 means that each input sequence will consist of data from 30 consecutive time steps.
- `num_features`: Indicates the number of features used in the dataset, which is 5 in this case. 
  
- `split_ratio`: A dictionary that defines the proportion of the dataset to be used for training, validation, and testing. Here, 70% of the data is allocated for training, 10% for validation, and the remaining 20% for testing.

####  Trimming the Dataset
To ensure that the dataset can be divided evenly by the `time_step`,  the code trims the dataset to a size that is divisible by 30. This step ensures that every sequence used for training or testing is complete and contains exactly 30 time steps.
```bash
trimmed_size = len(scaled_features) - (len(scaled_features) % time_step)
trimmed_data = scaled_features[:trimmed_size]
```

#### Calculate Spliting Indices
```bash
train_size = int(trimmed_size * split_ratio['train'])
validation_size = int(trimmed_size * split_rati['validation'])
test_size = trimmed_size - train_size - validation_size
```

The dataset is split into training, validation, and test sets using the calculated sizes:
```bash
train_data = scaled_features[:train_size]
validation_data = scaled_features[train_size:train_size + validation_size]
test_data = scaled_features[-test_size:]
```

- `train_data`: Used for training the model.
- `validation_data`: Used for validating the model's performance during training.
- `test_data`: Used for evaluating the model's performance on unseen data.

Once all these paramters has been defines everthing is ready to split de dataset, for this purpose it is going to be used the function `create_dataset` :
```bash
 def create_dataset(self,data, time_step):
            X, Y = [], []
            for i in range(len(data) - time_step):
               X.append(data[i:(i + time_step), :])
               Y.append(data[i + time_step, 0]) 
            
               return np.array(X), np.array(Y)
```
This method iterates over the data array, constructing input sequences (X) and the corresponding labels (Y) for the model:

X: For each iteration i, a slice of the data array from i to `i + time_step` is taken. This slice represents a sequence of `time_step` consecutive time steps, which serves as one input example for the model. These sequences are appended to the list `X`.

 Y: The label for each input sequence is the value immediately following the sequence in the dataset. Specifically, `data[i + time_step, 0]` is used as the label for the sequence ending at `i + time_step - 1`. This means the model is trained to predict the next value in the series based on the preceding `time_step` values. The labels are appended to the list `Y`.

 Now using this function, it is goin to bre created the three data set and and give them the shape that  our ML require as input, that will be a threedimensional array with the batch size, time step and the number of features.

```bash
 X_train, Y_train = self.create_dataset(train_data, time_step)
 X_train = np.reshape((X_train.shape[0], time_step, num_features))
 Y_train = train_data[time_step:, 0]

 X_validation, Y_validation = self.create_dataset(validation_data, time_step)
 X_validation = np.reshape(X_validation, (X_validation.shape[0],  time_step, num_features))
 Y_validation = validation_data[time_step:, 0]

 X_test, Y_test =self.create_dataset(test_data, time_step)
 X_test = np.reshape(X_test, (X_test.shape[0],  time_step, num_features))
 Y_test = test_data[time_step:, 0]
 ```
Now the data set is ready to be intrepreted by the machine learning models.

## Machine Learning 
 ### Deep Learning
In order to understand the implementation of machine learning, it is required first to grasp what Deep Learning encompasses. Deep Learning is a subset of machine learning that employs algorithms inspired by the structure and function of the brain called artificial neural networks. It has revolutionized various fields by providing solutions to complex problems that were previously considered intractable.

Some of the most popular DL architectures ara Convolutiona Neural Networks (CNN) for image or video processing and Recurrent Neural Networks (RNN) for sequential data processing, 

### RNN
RNNs, unlike traditional neural networks,  process data in sequence allowing previous outputs to influence the next input. This makes RNNs ideal for time series analysis, natural language processing, and other tasks where context and order matter.are pivotal in handling sequential data, excelling in tasks where context and the sequence of information are crucial. 

However, RNNs encounter a significant challenge known as the "vanishing gradient problem." This issue arises during the training phase, particularly with long sequences of data. As the sequence length increases, the gradients used in the training process can become very small, effectively preventing the network from learning long-distance correlations in the data. This limitation severely restricts the practical applications of traditional RNNs, making it difficult for them to process sequences with long-term dependencies.

To overcome these limitations, two advanced architectures have been developed: Long Short-Term Memory (LSTM) units and Gated Recurrent Units (GRU).

### LSTM (Long Short-Term Memory):
 LSTMs are designed with the specific goal of avoiding the long-term dependency problem.  This model employs a memory cell to store and retrieve input from earlier time steps, making it well-suited for modeling sequential data with long-term dependencies. It comprises four main components: three gates (Input, Output, and Forget gates) and a memory cell.

- The input gate governs the entry of fresh inputs into the memory cell.
- The forget gate determines how much of the previous memory state should be forgotten by the memory cell.
- The output gate regulates the output of memory cell states.
- The memory cell retains and transmits data to the next time step. 
  
These gates collectively decide which information should be passed through the network, which should be retained in the network's long-term memory, and which should be forgotten. This architecture allows LSTMs to maintain a balance between the short-term and long-term information, enabling them to capture dependencies that span across long sequences of data effectively.
The LSTM's ability to maintain a memory and selectively update it through these mechanisms enables it to handle various sequence learning tasks with high efficiency.

Architecture of LSTM

This adragam represents a architecture of the LSTM unit features:

- A cell state line that runs horizontally from left to right, denoted as `C_{t-1}` to `C_t`, which carries information across time steps and can be modified by three gates:
  
  1. **Forget Gate (`f_t`)**: Uses the sigmoid function (σ) to decide what information is discarded from the cell state, based on the previous hidden state `h_{t-1}` and the current input `X_t`.
  
  2. **Input Gate (`i_t`) and Candidate Layer (`C_t`)**: Determine which new information is added to the cell state. The input gate controls the values to be updated, and the candidate layer proposes new candidate values.
  
  3. **Output Gate (`o_t`)**: Decides the next hidden state (`h_t`), which is the filtered cell state. The sigmoid gate's output is multiplied by the `tanh` of the cell state to produce the hidden state `h_t`.

- Element-wise multiplication (×) for gating and element-wise addition (+) for updating the cell state and creating the output.

### GRU (Gated Recurrent Unit): 

GRUs simplify the LSTM architecture while retaining its ability to handle long-term dependencies. GRUs combine the forget and input gates into a single update gate and merge the cell state and hidden state, resulting in a more streamlined model that requires fewer parameters. Despite their simplicity, GRUs have demonstrated a capability comparable to LSTMs for many tasks, making them a popular choice due to their efficiency and effectiveness.
It is composed by the two gates (update gate and reset gate).

- The update gate determines how much of the past state should be kept and how much new input should be added to the existing state
- The reset gate regulates how much of the prior state is forgotten before absorbing the incoming input.

Architecure of GRU

The diagram above represents the achitecture of a GRU: 

1. **Update Gate (`z[t]`):** 
   - Uses the sigmoid function `σ` to determine how much of the past hidden state `h_{t-1}` should be retained.
   - It influences the extent to which the new hidden state `h_t` is just the old state `h_{t-1}` and how much it is the new candidate hidden state `~h_t`.

2. **Reset Gate (`r[t]`):**
   - Also utilizes the sigmoid function `σ` to control how much of the past hidden state `h_{t-1}` should be considered in creating the new candidate hidden state.
   - It can effectively remove the influence of the previous hidden state by setting its output close to 0.

3. **Candidate Hidden State (`~h_t`):**
   - Combines the current input `X_t` with the reset gate-modified previous hidden state.
   - The combination goes through a `tanh` function, proposing what the new hidden state could be.

4. **Hidden State (`h[t]`):**
   - Is the final state for the current timestep, calculated as a weighted average of the previous hidden state and the candidate hidden state, where weights are given by the update gate `z[t]`.
   - It represents the memory of the GRU cell at the current timestep.

The GRU uses element-wise operations:
- Element-wise multiplication (×) for the gating mechanisms (`z[t]` and `r[t]` gates).
- Element-wise addition (+) for updating the hidden state to get `h[t]`.

### Initialize LSTM 

- An LSTM model is instantiated using the Sequential class, which allows for the linear stacking of layers.
- The LSTM layer is added with na units (neurons), where na=50. This parameter defines the dimensionality of the output space or the number of hidden units in the LSTM layer. The input shape is specified as (time_step, num_features), indicating the dimensions of the input sequences.

Two Dense layers are added subsequently:
  - The first Dense layer has a single unit and is typically used for regression tasks or as a precursor to a final classification layer.
  - The second Dense layer, defined by units=dim_exit (where dim_exit=1), suggests the model's output dimension. In this context, it's configured to output a single value, fitting the regression task's requirements.
- The model is compiled with the Adam optimizer and mean squared error (mse) as the loss function, setting up the model for training.

```bash
#LSTM
 LSTM_model = Sequential()
 LSTM_model.add(LSTM(units=na, input_shape=(time_step, num_features))) 
 LSTM_model.add(Dense(1))
 LSTM_model.add(Dense(units=dim_exit))
LSTM_model.compile(optimizer='adam',loss='mse')
```
  
### Initialize GRU 

The GRU model architecture is similar to the LSTM's but utilizes GRU layers. GRUs offer a simplified mechanism with fewer parameters compared to LSTMs, potentially leading to quicker training times while effectively capturing time-dependent information.

- Constructs a `Sequential` GRU model, beginning with a GRU layer of 50 units and the specified input shape.
- Follows the same structure with Dropout and Dense layers as the LSTM model for consistency.
- Compiles with the same `adam` optimizer and `mse` loss function, aligning with the regression objective.

```bash
 #GRU
RU_model= Sequential()
GRU_model.add(GRU(units=na, input_shape=(time_step, num_features)))
GRU_model.add(Dense(1))
GRU_model.add(Dense(units=dim_exit))
GRU_model.compile(optimizer='adam',loss='mse')
```

### Training
The training process is the same for both models
- Trains using the `fit` method on `X_train` and `Y_train` for training data and labels, respectively.
- Training runs for 50 epochs (`epochs=50`) with a batch size of 64 (`batch_size=64`).
- Employs `validation_data` for performance evaluation on a separate dataset after each epoch.
- Sets `verbose=1` for detailed logging of the training progress.
- Utilizes `callbacks` for training monitoring

```bash
# LSTM training
 history_LSTM=LSTM_model.fit(X_train,Y_train,epochs=epochs,batch_size=batch_size,validation_data=(X_validation, Y_validation),callbacks=callbacks,verbose=1)

# GRU trainin
history_GRU=GRU_model.fit(X_train,Y_train,epochs=epochs,batch_size=batch_size,validation_data=(X_validation, Y_validation),callbacks=callbacks,verbose=1)
  ```

## Generating Predictions

- **LSTM Predictions**: `LSTM_model.predict(X_test)` is used to generate predictions from the LSTM model using the test dataset (`X_test`). These predictions are initially in the scaled form because the model was trained on data that had been normalized.

- **GRU Predictions**: Similarly, `GRU_model.predict(X_test)` generates predictions for the same test dataset using the GRU model. As with the LSTM predictions, these are also in the scaled form.

### Inverse Scaling of Predictions

Since the original dataset was normalized to a specific range (typically 0 to 1) to facilitate model training, the predictions made by the models are also in this scaled range. To interpret these predictions in the context of actual Bitcoin prices, it is necessary to reverse the scaling process.

- **Inverse Scaling for LSTM Predictions**: `scaler_price.inverse_transform(LSTM_predic)` converts the LSTM model's predictions from the normalized scale back to their original price scale. This step is crucial for comparing the predicted prices against real historical data.

- **Inverse Scaling for GRU Predictions**: Similarly, `scaler_price.inverse_transform(GRU_predic)` is used to reverse the normalization applied to the GRU model's predictions, transforming them back to the original price scale.

```bash
 # Making predictions
 LSTM_predic = LSTM_model.predict(X_test)
 GRU_predic = GRU_model.predict(X_test)

 # Inverse transforming the predictions to get them back to the original scale
 LSTM_price_predictions_scaled = scaler_price.inverse_transform(LSTM_predic)
 GRU_price_predictions_scaled = scaler_price.inverse_transform(GRU_predic)
 
  ```

  After training the LSTM and GRU models to forecast Bitcoin prices, it's crucial to evaluate their performance using various metrics. This section covers the evaluation of both models on the test dataset, employing several statistical measures to assess their predictive accuracy and effectiveness.

### LSTM Model Evaluation

The LSTM model's performance is evaluated using the following metrics:

 **Root Mean Square Error (RMSE)**: Reflects the square root of the average of the squares of the differences between predicted and actual values.
 
$$ 
\text{RMSE} = \sqrt{\frac{1}{n} \sum_{i=1}^{n} (y_{\text{true},i} - y_{\text{pred},i})^2} 
$$

  - `LSTM Test data RMSE`: Calculated using `math.sqrt(mean_squared_error(Y_test, LSTM_predic))`.

  **Mean Squared Error (MSE)**: Indicates the average of the squares of the differences between predicted and actual values.

$$ 
 \text{MSE} = \frac{1}{n} \sum_{i=1}^{n} (y_{\text{true},i} - y_{\text{pred},i})^2 
$$

  - `LSTM Test data MSE`: Obtained with `mean_squared_error(Y_test, LSTM_predic)

- **Mean Absolute Error (MAE)**: Measures the average of the absolute differences between predicted and actual values.
 
$$ 
\text{MAE} = \frac{1}{n} \sum_{i=1}^{n} |y_{\text{true},i} - y_{\text{pred},i}| 
$$

  - `LSTM Test data MAE`: Derived from `mean_absolute_error(Y_test, LSTM_predic)`.

 **Explained Variance Regression Score**: Provides a measure of how well the model accounts for the variation in the dataset.

$$
 \text{Explained Variance} = 1 - \frac{\text{Var}(y_{\text{true}} - y_{\text{pred}})}{\text{Var}(y_{\text{true}})} 
$$

  - `LSTM Test data explained variance regression score`: Calculated using `explained_variance_score(Y_test, LSTM_predic)`.

**R² Score (Coefficient of Determination)**: Indicates the proportion of the variance in the dependent variable that is predictable from the independent variables.

$$
 R^2 = 1 - \frac{\sum_{i=1}^{n} (y_{\text{true},i} - y_{\text{pred},i})^2}{\sum_{i=1}^{n} (y_{\text{true},i} - \bar{y}_{\text{true}})^2} 
$$

  - `LSTM Test data R2 score`: Computed with `r2_score(Y_test, LSTM_predic)`.

**Mean Gamma Deviance Regression Loss (MGD)**: A metric for regression models that predict positive continuous outcomes based on the gamma distribution.

$$
\text{MGD} = \frac{2}{n} \sum_{i=1}^{n} \left( \log \left( \frac{y_{\text{pred},i} + \text{offset}}{y_{\text{true},i} + \text{offset}} \right) + \frac{y_{\text{true},i} - y_{\text{pred},i}}{y_{\text{true},i} + \text{offset}} \right) 
$$

  - `LSTM Test data MGD`: `mean_gamma_deviance(Y_test, LSTM_predic)`

 **Mean Poisson Deviance Regression Loss (MPD)**: A metric for regression models that predict count data using the Poisson distribution.

$$ 
\text{MPD} = \frac{2}{n} \sum_{i=1}^{n} \left( y_{\text{true},i} \cdot \log \left( \frac{y_{\text{true},i}}{y_{\text{pred},i}} \right) - (y_{\text{true},i} - y_{\text{pred},i}) \right) 
$$

- `LSTM Test data MPD`: `mean_poisson_deviance(Y_test, LSTM_predic)`

### GRU Model Evaluation

The GRU model undergoes a similar evaluation process:

- **RMSE for GRU Model**: `GRU Test data RMSE`
- **MSE for GRU Model**: `GRU Test data MSE`
- **MAE for GRU Model**: `GRU Test data MAE`
- **Explained Variance for GRU Model**: `GRU Test data explained variance regression score`
- **R² Score for GRU Model**: `GRU Test data R2 score`
- **MGD for GRU Model**: `GRU Test data MGD`
- **MPD for GRU Model**: `GRU Test data MPD`

By evaluating both models using these comprehensive metrics, we can assess their predictive accuracy and understand their strengths and limitations in forecasting Bitcoin prices.

## Generating Future Predictions with LSTM and GRU Models

After evaluating the LSTM and GRU models on historical test data, the next step involves using these models to predict future Bitcoin prices. The process entails preparing the input data from the recent past and iteratively predicting the next day's price over a specified future period.

### Preparing the Input Data

- **Time Window for Predictions**: The model looks back 90 days (`time_based = 90`) from the most recent data point in `test_data` to prepare the input for the first prediction. This approach assumes that the last 90 days contain relevant information for forecasting future prices.

- **Reshaping the Data**: The selected 90-day data segment is reshaped to match the expected input format for the LSTM and GRU models, which is `(1, time_based, num_features)`. This step ensures compatibility with the model's architecture, allowing for accurate predictions.
  
 ```bash

 # Number of days to look back to make future predictions
  time_based = 90
 # Prepare the input for the first prediction by taking the last 90 days from test_data
 last_90_days = test_data[-time_based:]
 # Reshape the last 90 days data to fit the LSTM_model's expected input shape
  current_batch = last_90_days.reshape((1, time_based, num_features))
```
### Iterative Future Predictions

- Two lists, `LSTM_future_predictions` and `GRU_future_predictions`, are initialized to store the models' predictions for the next 30 days.

- **Prediction Loop**: For each day in the next 30 days:
  - The LSTM and GRU models each make a prediction for the next day's price using `current_batch` as input.
  - These predictions are appended to their respective lists for future analysis.
  - The input batch is then updated to include the new prediction while dropping the oldest day. This process involves:
    - Extracting features from the last day in the batch (excluding the predicted feature).
    - Combining these features with the new prediction to form the next day's input.
    - Reshaping and updating the input batch to reflect this addition, ensuring the batch always represents the most recent 90 days of data relevant for prediction.

 ```bash
# Predict the next 30 days
        for i in range(30):  # Loop for 30 days
            # Predict the next day using the first LSTM_model
            LSTM_next_day_prediction = LSTM_model.predict(current_batch)[0]
            # Predict the next day using the second LSTM_model
            GRU_next_day_prediction = GRU_model.predict(current_batch)[0]
            # Add the predictions to their respective lists
            LSTM_future_predictions.append(LSTM_next_day_prediction)
            GRU_future_predictions.append(GRU_next_day_prediction)
    
            # Get the features from the last day in the batch (excluding the target feature)
            last_features = current_batch[0, -1, 1:]
    
            # Combine the next day prediction with the last features
            next_day_input = np.hstack([LSTM_next_day_prediction, last_features])
            # Reshape the combination to match the expected number of features
            next_day_input = next_day_input.reshape((1, 1, num_features))
            # Update the batch to include the new prediction and drop the oldest day
            current_batch = np.concatenate([current_batch[:, 1:, :], next_day_input], axis=1)

            # Repeat the process for  GRU model prediction
            GRU_next_day_input = np.hstack([GRU_next_day_prediction, last_features])
            GRU_next_day_input = GRU_next_day_input.reshape((1, 1, num_features))

```
### Rescaling Predictions

- **Inverse Scaling**: The predictions made by the models are initially in the scaled form (due to preprocessing). To interpret these predictions in the context of actual Bitcoin prices, they are inversely transformed back to their original scale using `scaler_price.inverse_transform`.

- The `LSTM_future_predictions_scaled` and `GRU_future_predictions_scaled` arrays contain the rescaled predictions for the next 30 days, providing a forecast of Bitcoin prices in a usable format.
```bash
  # Reverse the scaling transformation to convert predictions back to their original scale
        LSTM_future_predictions_scaled = scaler_price.inverse_transform(np.array(LSTM_future_predictions).reshape(-1, 1))
        GRU_future_predictions_scaled = scaler_price.inverse_transform(np.array(GRU_future_predictions).reshape(-1, 1))
 ```

## Results
The graphical results demonstrate that both machine learning models achieve a high level of accuracy when compared with the actual prices. However, it is observed that the LSTM model exhibits a degree of imprecision towards the end.



While testing the results using evaluation metrics is given that:
- According RMSE  GRU is  more accurate
- According MSE  GRU is more accurate
- According MAE  LSTM is more accurate
- According Varicence regression  GRU is more accurate
-  According R2  GRU is more accurate
-  According MGD  GRU is more accurate
-  According MSE  LSTM is more accurate

| Metric | LSTM Results | GRU Results |
|---|---|---|
| Test data RMSE: | 0.013515279041348916 | 0.012886921913316975 |
| Test data MSE: | 0.0018266276762337735 | 0.001660727563992923 |
| Test data MAE: | 0.008977291327245784 | 0.00988896278501512 |
| Test data variance regression :| 0.9933846879800868 | 0.9955477868417992 |
| Test data R2 score: | 0.9933206066938037 | 0.9939272503512039 |
| Test data MGD: | 0.0008894913516761145 | 0.0009750636990728198 |
| Test data MPD: | 0.0036820411478632367 | 0.00037713497773401283 |



## Conlusion 
The LSTM and GRU models have been employed to forecast future Bitcoin prices, and their performance was rigorously evaluated. The evaluation metrics show that both models achieve a high degree of accuracy, with the GRU model displaying a slight edge in terms of lower RMSE, MSE, and higher R² score, indicating a marginally better fit to the test data. 

The explained variance scores are impressively high for both models (LSTM: 0.9933, GRU: 0.9955), suggesting that they are highly capable of capturing the variance in the Bitcoin price movements.

From the predictive visualizations, it is observed that the GRU model's predictions are a bit closer to the actual price trends. However, the difference is not substantial, implying that in different market conditions or with different hyperparameter tunings, the LSTM model might perform equally well or even outperform the GRU model.

In conclusion, while the GRU model currently shows slightly more accurate results, both models are quite competent in predicting Bitcoin prices. The choice between LSTM and GRU for future predictions might depend on computational resources, time constraints, and specific nuances in the price movement patterns. There is a strong likelihood that under other circumstances, the LSTM model could yield better results, underlining the importance of model experimentation and validation in practical scenarios.
  
## References
1. https://hpc.uni.lu/infrastructure/network
2. https://dlcdnimgs.asus.com/websites/global/aboutASUS/OS/Linux_Status_report_202312.pdf
3. https://www.diva-portal.org/smash/get/diva2:1778251/FULLTEXT03
4. https://plantuml.com/
5. https://www.kaggle.com/code/meetnagadia/bitcoin-price-prediction-using-lstm

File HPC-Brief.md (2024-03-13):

# ELEE1119 Assignment Brief: High-Performance Computing System Design and Implementation

**Submission Date: 27th March 2024 @ 1500**

**Viva: 27th March 2024 @ 1530-1620**

**Weighting: 60%**

---

## Introduction

In the field of advanced computer engineering, collaborative projects in large teams are commonplace. This coursework aims to simulate such an experience by requiring you to conceive, design, implement, and operate a project using various hardware provided by the University of Greenwich.

### Objectives

1. **Conception:** Conceive a scenario where Single Board Computers, Robotic Arms, Robotic Vehicles, Flick (e-field), Webcams, Touchscreens, Azure development kit, sensors, actuators, and other components complement each other.

2. **Team Structure:** Nominate a project manager to oversee the entire project and initialize a GitHub repository for collaborative development.

3. **Development:** Break the team into sub-teams, each responsible for developing a specific part of the project. Ensure all sub-parts seamlessly work together in the finished project.

4. **Documentation:** Add all code and documentation to the GitHub repository, maintaining an organized structure with branches for development and subsequent merges.

5. **Presentation:** Deliver a video viva presentation following the flow of an engineering report: introduction, problem analysis, problem solution, results, discussion, and conclusion.

## Hardware and Software

### Hardware

- Mother/Single Board Computers (e.g., Raspberry Pis, Jetson Nanos, Odriod, Rock, ASUS CS-8 motherboards)
- PSU
- SD/SSD
- Keyboard/Mouse
- WiFi dongle
- Ethernet cables
- 3D printing - material
- laser cutting - material
- fans
- mineral oil?

### Software

- Languages: Python, Shell, C/C++/C#, and any others deemed appropriate
- Git
- Github
- Slurm, singularity, Jack the Ripper etc

## Deliverables/Tasks

1. **System Design and Architecture:**
   - Design the architecture, integrating 14 ASUS CS-8 motherboards and single-board computers.
   - Provide critical reflections on the chosen design.

2. **Technology Research:**
   - Conduct comprehensive research on HPC technologies, power management, non-volatile storage, and RAM.
   - Justify technology choices based on problem domain appropriateness.

3. **System Construction:**
   - Assemble the HPC system, implementing power management and resource-efficient configurations.
   - Configure non-volatile storage and RAM to meet performance requirements.

4. **Housing and Cooling Solutions:**
   - Design and implement housing/structure using laser cutting or additive manufacturing.
   - Discuss convection principles (natural and forced) for cooling.

5. **Operating System Selection:**
   - Choose an operating system (e.g., Linux - Ubuntu or declarative system - NixOS).
   - Justify the choice based on task requirements and overall design.

6. **Task Implementation:**
   - Configure the single-board computer as the head node with WiFi access.
   - Implement tasks such as password cracking, DNA sequencing, and weather prediction using relevant packages/libraries (e.g., slurm, singularity).

7. **Performance Evaluation:**
   - Develop a strategy for evaluating HPC system performance.

8. **Software and OS Maintenance:**
   - Implement a system for updating software and the operating system using cron and Git.
   - Reflect on the importance of software and OS maintenance in an HPC environment.

You will work as one team to conceive a scenario that the components provided to you can compliment.   

In this initial stage you will nominate a project manager to oversee the entire project and be responsible for initialising the GitHub repository through which you will all contribute through. 

The team will be broken down into sub teams whose tasks will be to develop a specific part of the project. All the sub parts should work together in the finished project.  

All code and documentation must be added to the Github repository, and the Github repository should have a sufficient number of branches for project development and subsequent merges to the ‘main’ branch as the project develops. 

A video viva presentation must be delivered that includes; a suitable logo, development of the project and final working demonstration. The format of the video should follow the flow of an engineering report: introduction, problem analysis, problem solution, results, discussion and conclusion.  

Video must be uploaded to private channel YouTube and shared via link using the **[Coursework Submission Document](https://moodlecurrent.gre.ac.uk/mod/resource/view.php?id=2526729)**

## Assessment Criteria

- Assessment based on critical thinking, technical implementation, documentation quality, and teamwork/self-evaluation.
- Detailed rubric provided for both group and individual assessments.

---

This assignment challenges your understanding of computer architecture, system design, and collaborative project implementation. If questions arise or clarification is needed, contact your module leader. Best of luck!

## Rubric in Full
    
<div align=center>

 **Rubric for : Group Assessment (60%)**

| Criteria | Excellent (9-10) | Proficient (6-8) | Basic (3-5) | Limited (0-2) |
|---|---|---|---|---|
| **Clearly Defined Coursework Scope** | Clearly defines the coursework scope with precision and detail. | Defines the coursework scope effectively. | Defines the coursework scope with some gaps or ambiguity. | Fails to define the coursework scope adequately. |
| **Clear Breakdown of Workload** | Provides a clear and well-structured breakdown of workload for each team/member. | Offers a clear breakdown of workload with acceptable structure. | Presents a breakdown of workload with some gaps or lack of clarity. | Fails to provide a clear breakdown of workload. |
| **Technical Content** | Demonstrates a high level of technical content with depth and sophistication. | Presents technical content at a proficient level. | Provides technical content with some gaps or limited depth. | Technical content is insufficient or poorly presented. |
| **Depth of Discussion** | Engages in a thorough and insightful discussion, demonstrating a deep understanding of the project. | Provides a good level of discussion with reasonable insights. | Offers a discussion with some gaps or lacks in-depth insights. | Discussion is minimal or lacks depth. |
| **Clarity of Presentation** | Delivers a presentation with exceptional clarity, structure, and coherence. | Presents information with clear organization and coherence. | Presentation has some organizational issues or lacks clarity at times. | Presentation is disorganized and challenging to follow. |
| **Working Demonstration of Project** | Showcases a fully functional and well-demonstrated project with excellence. | Demonstrates a working project effectively. | Provides a working demonstration with some issues or limitations. | Fails to provide a satisfactory working demonstration. |
| **GitHub Fully Setup** | Sets up GitHub repository fully, with branches and effective project management. | Sets up GitHub repository well, with acceptable project management. | Sets up GitHub with some issues or lacks effective project management. | GitHub setup is inadequate or poorly managed. |
</div>

--------------

<div align=center>

 **Rubric for : Individual Assessment (40%)**

| Criteria| Excellent (9-10) | Proficient (6-8) | Basic (3-5) | Limited (0-2) |
|---|---|---|---|---|
| **Consistent Contribution via Git**| Consistently contributes to the project through Git with a high level of engagement. | Makes regular and effective contributions to the project via Git. | Contributes to the project via Git with some irregularities or inefficiencies. | Contribution to the project via Git is inconsistent or ineffective. |
| **Quality of Documentation**| Provides documentation of exceptional quality, adhering to industry conventions. | Delivers documentation of good quality, following industry conventions. | Documentation has some issues or lacks completeness. | Documentation is of poor quality or incomplete. |
| **- README (50%)**| The README is well-structured, comprehensive, and provides essential project information. | The README is adequately structured and contains most essential project information. | The README is somewhat disorganized or lacks some essential project information. | The README is disorganized or missing crucial project information. |
| **- Code Documentation (50%)**| Code documentation is thorough, clear, and follows industry standards. | Code documentation is sufficient, clear, and follows industry standards. | Code documentation has some gaps or lacks clarity. | Code documentation is inadequate or unclear. |
| **Video Viva Q&A**| Engages effectively in the video viva Q&A, providing insightful and articulate responses. | Participates well in the video viva Q&A with clear and thoughtful responses. | Responds to video viva Q&A with some gaps or lacks clarity. | Video viva Q&A responses are unclear or incomplete. |

</div>

_ **The HPC'S purpose** _

_ **There are three sub-components to the HPC'S purpose in order for it to function fully.** _

- _Background information on each selected crypto_
- _Recent fluctuations in the price and trading patterns_
- _Predicted outcomes and investment recommendation_
- _Choose operating system for Hpc_

_ **Background information on each selected crypto** _

_Cryptocurrency is a digital asset that is secured by cryptography. This type of money allows for decentralized transactions, meaning that a central authority, such as a bank, does not handle, verify, or regulate the transactions. An example of the information that the HPC could collect are, when the currency was made, how much its currently worth and the advantage and disadvantages to it like where it is and isn't accepted_

_ **Recent fluctuations in the price and trading patterns** _

_It is not unusual for the price of Bitcoin (BTC 0.72%) to fluctuate by 5% or even 10% every day. Wider price fluctuations can occur with smaller coins. because supply and demand, investors and users' mood, laws, and media hype all have an impact. All these elements work together to cause price volatility. This will show use if the coin is on the right trajectory or if we should cut our losses_

_ **Predicted outcomes and investment recommendation** _

_In order for the HPC to figure out how to give suggestion that track with the current stats of the coin we will have to utilize machine learning.__A field of computer science and artificial intelligence (AI) called "machine learning" focuses on using data and algorithms to simulate human learning processes and progressively increase their accuracy. By using machine learning we can utilize the information we gathered in the first two step to create an algorithm that can not only get you when to invest but how to invest with the hope that this will limit the risk in error my taking out the human error possibility_

_ **Combined step** _

_Once all the above steps are combined, we should have a HPC that will be able to select and recommend cryptocurrency as well as improve itself the more and more the machine is used_

_ **Software languages for a HPC** _

_ **Fortran** _

Fortran (Formula Translation) is one of the oldest high-performance programming languages and is widely used in scientific computing. It is designed to handle complex numerical calculations and has built-in support for parallel processing. Fortran is known for its excellent performance, especially for scientific applications.

**Pros**

- Built-in support for parallel processing
- Can handle complex calculations
- Mature and stable language with decades of development and optimization
- Excellent performance in numerical computing

**Cons**

- Limited functionality for non-numerical tasks
- The syntax may be difficult for beginners to learn
- Limited libraries for non-scientific tasks.
- Lack of modern features found in newer programming languages

**C#/C++**

C/C++ is another popular high-performance programming language used in scientific computing. It is a general-purpose language and is known for its speed, efficiency, and memory management/C++ is used extensively in scientific simulations and numerical computing.

**Pros**

- _High performance, efficient language._
- _Compilable to run on multiple platforms._
- _Numerous libraries and frameworks for scientific computing._
- _Better performance than interpreted languages._

_ **Cons** _

- _No automatic garbage collection, leading to memory leaks if not managed properly._
- _Prone to security vulnerabilities like buffer overflows._
- _Development and maintenance require more time and effort than higher-level languages._
- _Debugging can be more challenging and requires advanced programming skills._

_ **Python** _

_Python is a popular programming language used in scientific computing due to its simplicity, ease of use, and wide range of libraries. It is a high-level language and is widely used in data analysis, machine learning, and scientific computing. Python has built-in support for numerical calculations and visualization_.

**Pros**

- Easy to learn and use
- Widely used in scientific computing, data analysis, and machine learning
- Cross-platform compatibility
- Built-in support for numerical calculations and visualization
- A wide range of libraries and frameworks are available

**Cons**

- _Limited mobile app development support_
- _Not suitable for low-level programming_
- _Limited support for GUI development_

_ **HPC most used language** _

_The most popular high-productivity language in scientific computing is called Python. It's perfect for rapidly developing scalable apps because of its extensive library support and extremely easy syntax._

_In contrast to Julia, Python is not at all HPC capable. The kinds of data structures and other characteristics required for quick computations are not natively supported by the language. But over time, Python interfaces to several C/C++ libraries have been created, and Python now includes data types and algorithms for incredibly effective array operations thanks to the NumPy extension._

_Python today is the number one language for machine learning and many other demanding HPC applications._

_Although languages like c# and java outperform phyton in terms of speed and runtime performance. Phyton is more regularly used as it is faster to development in projects due to its ease of uses and it readability its many libraries also give python access to the same algorithms and data types as java and c_

_The next favorable language to use would be java.__Java code is consistently quicker than C code when program development is given the same window of operation. Java HPC makes perfect sense for code development and modification on a regular basis._

_Fortran is a highly recommended language to use also and was the go-to language for HPC'S. It was first created in 1957 and went on to dominate the computer science field for many years. However, with newer languages being developed Fortran became outdated and does not have the capability to keep up efficiently with the likes of java or python anymore_

_ **Other possibly relevant information** _

[_ **https://www.scientific-computing.com/tech-focus/latest-software-tools-HPC** _](https://www.scientific-computing.com/tech-focus/latest-software-tools-HPC)

[_ **https://www.hpe.com/uk/en/compute/hpc/hpc-software.html** _](https://www.hpe.com/uk/en/compute/hpc/hpc-software.html)

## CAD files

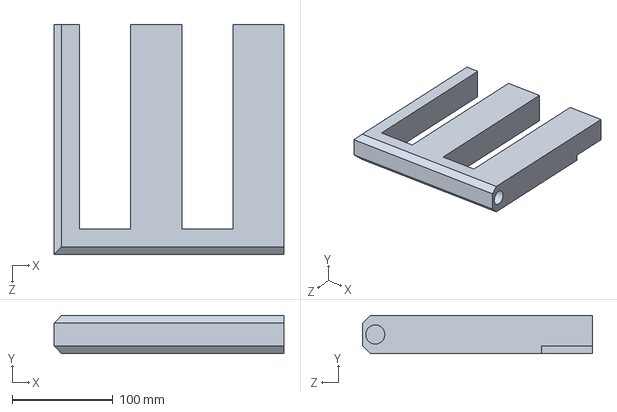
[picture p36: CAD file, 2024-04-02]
shelf part 4.SLDPRT
228.6 x 38.1 x 228.6 mm

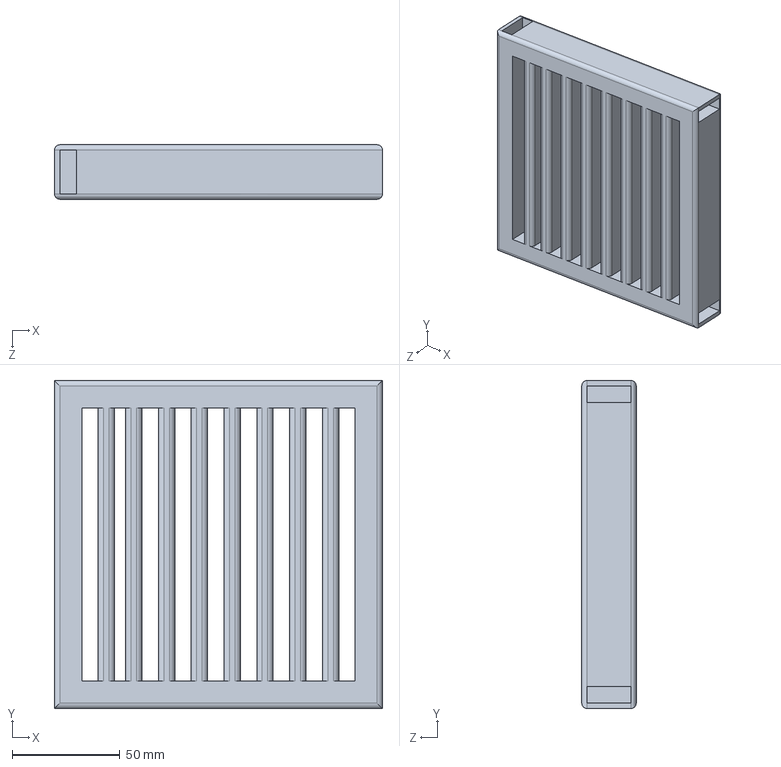
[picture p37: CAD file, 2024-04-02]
shelf piece 1.SLDPRT
152.4 x 152.4 x 25.4 mm

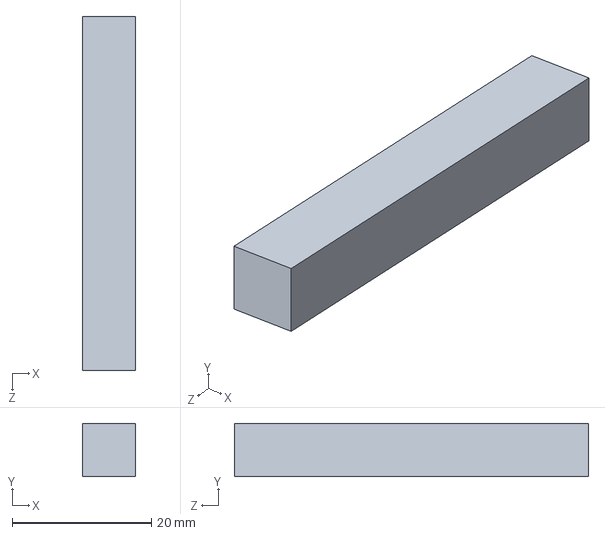
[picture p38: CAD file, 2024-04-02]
floor connectors.SLDPRT
7.62 x 7.62 x 50.8 mm

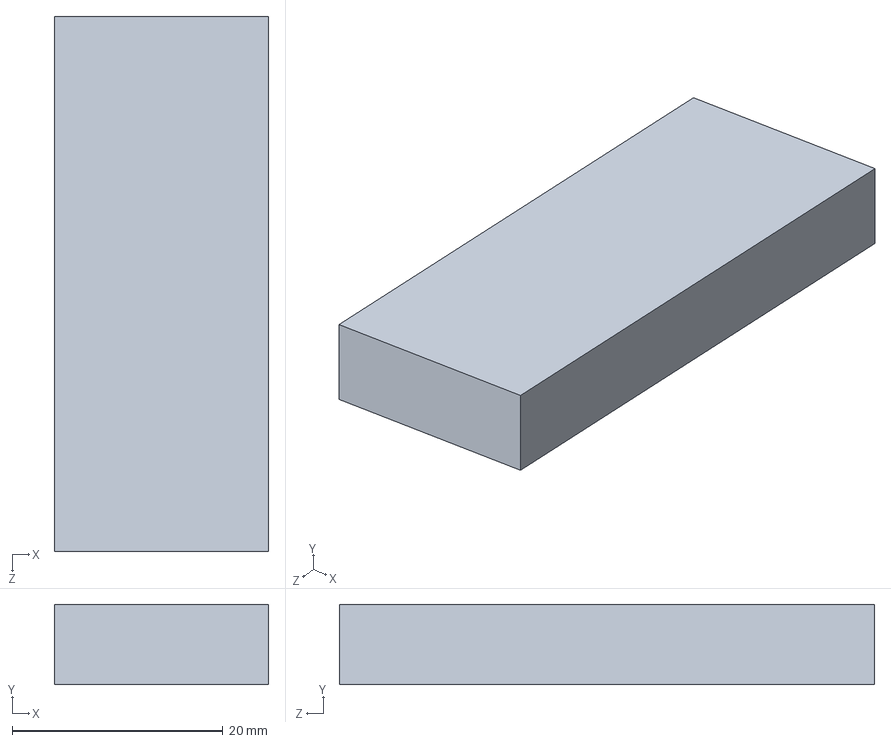
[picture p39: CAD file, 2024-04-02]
shelf piece 3.SLDPRT
20.3 x 7.62 x 50.8 mm

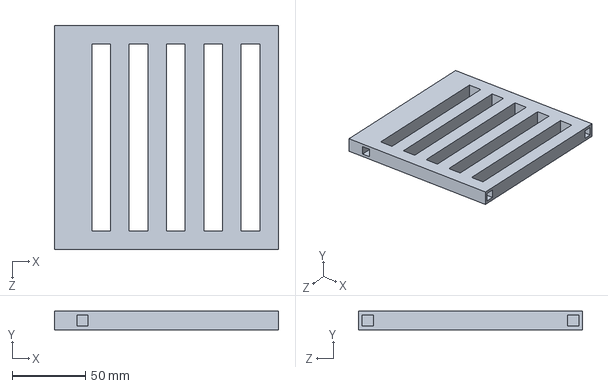
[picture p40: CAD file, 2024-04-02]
floor mid l.r.SLDPRT
152.4 x 12.7 x 152.4 mm

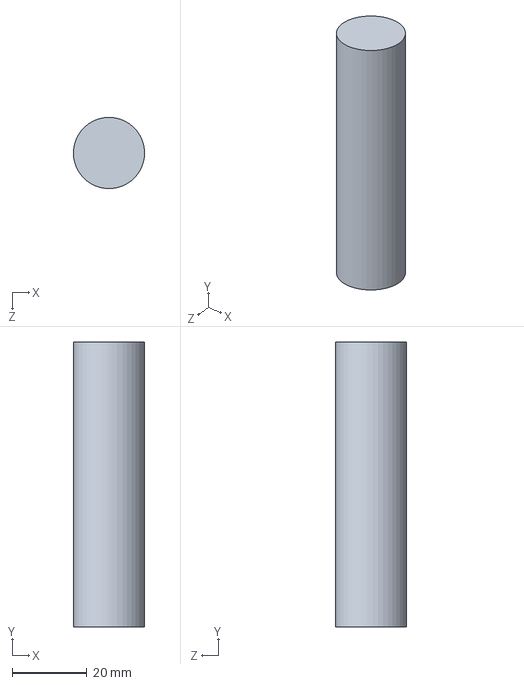
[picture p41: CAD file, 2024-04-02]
shelf part 3.SLDPRT
19.0 x 76.2 x 19.1 mm

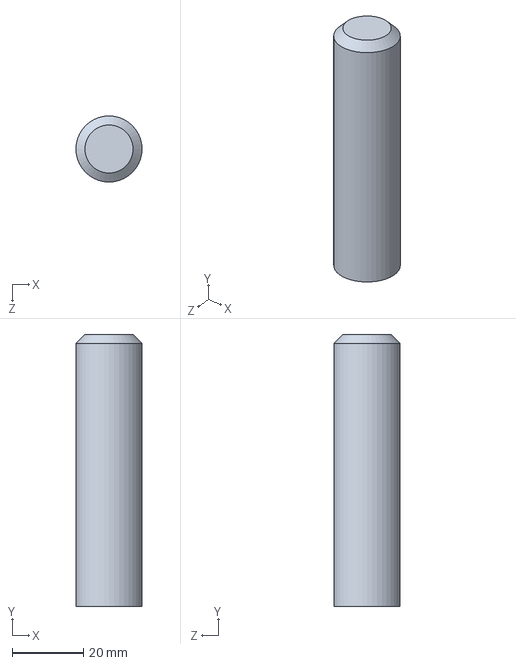
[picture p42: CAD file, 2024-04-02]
connectors.SLDPRT
18.5 x 76.2 x 18.5 mm

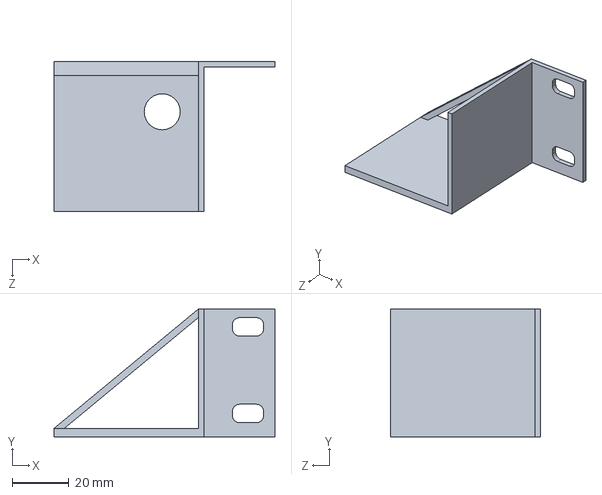
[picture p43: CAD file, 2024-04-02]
corner support back right SLDPRT.SLDPRT
77.8 x 45.0 x 52.8 mm

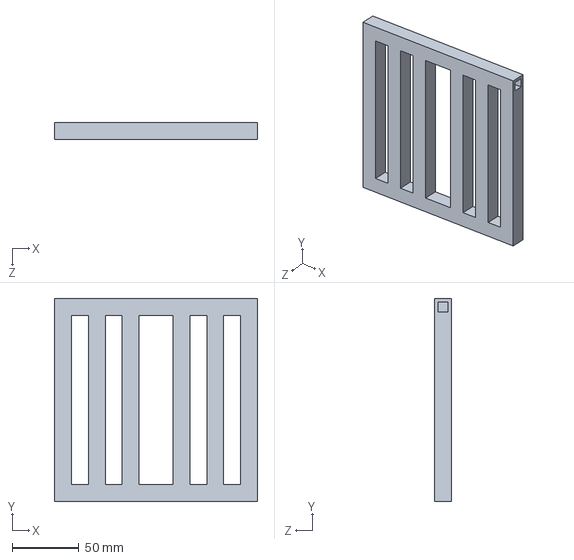
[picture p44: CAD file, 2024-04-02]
floor center.SLDPRT
152.4 x 152.4 x 12.7 mm

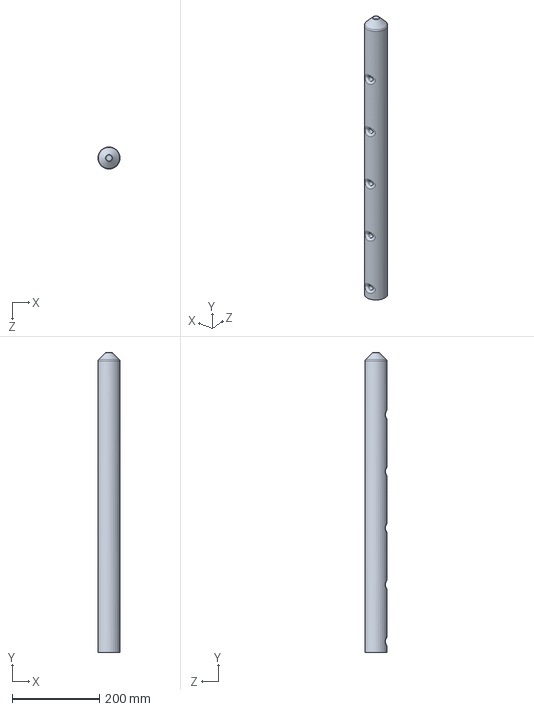
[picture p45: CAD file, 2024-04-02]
poles.SLDPRT
50.3 x 685.8 x 50.3 mm

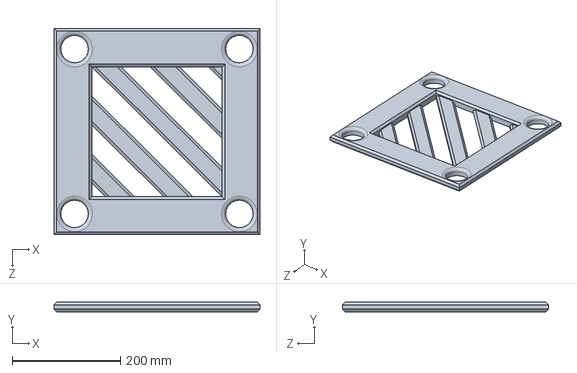
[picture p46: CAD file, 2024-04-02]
shelf.SLDPRT
381.0 x 18.4 x 381.0 mm

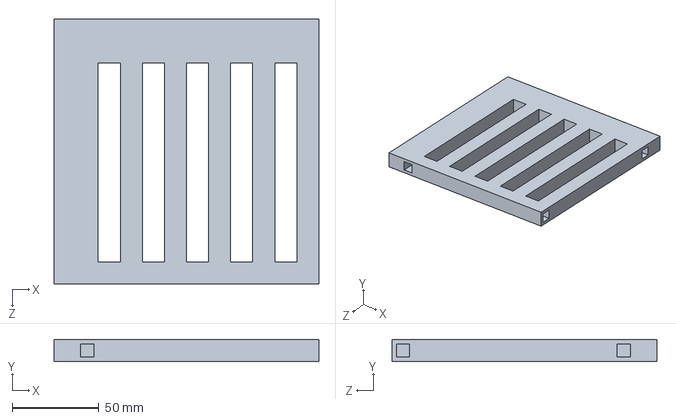
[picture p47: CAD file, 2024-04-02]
floor corner SLDPRT.SLDPRT
152.4 x 12.7 x 152.4 mm

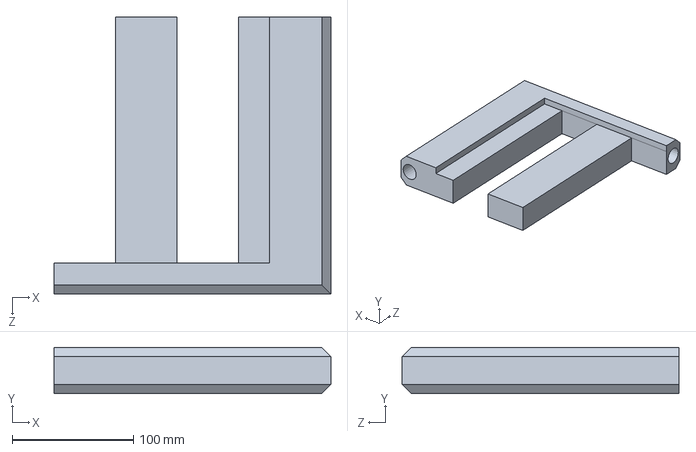
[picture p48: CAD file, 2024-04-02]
shelf part2.SLDPRT
228.6 x 38.1 x 228.6 mm

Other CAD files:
shelf piece 2.SLDPRT
shelf part 1.SLDPRT
floor midupper l.r.SLDPRT
corner support back left.SLDPRT
shelf part5.SLDPRT
shelf piece 4.SLDPRT

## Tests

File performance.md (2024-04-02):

# Performance Evaluation

As the HPC system was built for this project, a series of tests were conducted to evaluate its performance. The steps and guidelines described above, including networking, power on/off functions, prometheus, Grafana, the justification for choosing operating systems and designs’ tests have demonstrated that the specific tasks or designs function very well. With this knowledge, let's explore how the HPC system efficiently runs the application and performs predictions far better compared to general computers, such as laptops and desktops.

## 1. Timing for cryptocurrency prediction:
General Computer: 8 minute 49 seconds
HPC built in this project: 2 minute 48 seconds

## 2. Cores and processor used for cryptocurrency prediction:
General computer: 6 cores	(i5 processor 9th generation)
HPC built in this project: 16 cores  (4 X i5 processor 9th generation)

As, mentioned above, the cryptocurrency prediction in general computer, took 8 minutes 49 seconds (which has i5 processor 9th generation). Therefore, to enhance the performance of prediction, in this project number of motherboards were connected together and tested making HPC with modular design (increasing number of motherboards)

| No of motherboards used | 1 x i5 4th gen motherboard | 2 x i5 processor 9th generation | 3 x i5 processor 9th generation | i5 processor 9th generation |
|---|---|---|---|---|
| Time it took | 19 minutes 02 seconds | 14 minutes 03 seconds | 7 minutes 59 seconds | 2 minutes 48 seconds |

•	**Scalability:**
A crucial advantage of the HPC system over general computers is its scalability. The system has been designed with the ability to scale out by adding more nodes or scale up by enhancing existing nodes with more powerful components. This scalability ensures that as the complexity of the prediction models or the volume of data increases, the system can be expanded to maintain or even reduce computation times.

•	**Energy Efficiency:**
While the HPC system boasts a higher number of cores and substantially faster processing times, it's also designed with energy efficiency in mind. The choice of components and the system's architecture are optimized to balance high performance with energy usage, making it not only faster but also more cost-effective in terms of energy consumption compared to running similar tasks on general-purpose computers over extended periods.

The comparative analysis between the HPC system and a general-purpose computer highlights the former's superior performance, scalability, energy efficiency, reliability and networking capabilities. These attributes make the HPC system exceptionally well-suited for running complex and data-heavy applications, confirming its value and effectiveness for the project's objectives. Future work may focus on further optimizing these aspects, exploring additional computational models, and expanding the system's capabilities to address even more demanding computational challenges.

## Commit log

2024-02-11 power management research and documentation
2024-02-12 updates on Power Management
2024-02-12 Power Supply Unit Description added
2024-02-12 power on button research update 1
2024-02-12 power on button documentation update 2
2024-02-23 data saved in proper formatt
    [data.csv]
2024-03-04 python code, visualisation of current data
2024-03-19 Added Original cad designs for the floor of the case
    [floor center.SLDPRT, floor connectors.SLDPRT, floor corner SLDPRT.SLDPRT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]
2024-03-19 Added Original shelf pieces for the case as well as the pole connector poles
    [connectors.SLDPRT, poles.SLDPRT, shelf part 1.SLDPRT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]
2024-03-19 Added the corner brackets used in the active case
    [corner support back left.SLDPRT, corner support back right SLDPRT.SLDPRT]
2024-03-19 Power Consumption Calculation Added
2024-03-22 PXE BOOT: Installation of OS and Mounting part added: More to add.
2024-03-28 images of case in progress
2024-03-30 Calculation of Heat Dissipation. More to Add
2024-03-30 3D model of case with fan placement added
2024-03-30 powermanagement part deleted from cooling calculation branch to prevent conflict
2024-03-31 more information added about the fan. more to add
2024-03-31 Update README.md
    Added material issue and ventilation issue
2024-03-31 Update README.md
    Added reflection of design and a possible improvements as well as material information to consider
2024-03-31 Updated README.md, power management structure
2024-03-31 missing information added for fan, ready to be merged to dev
2024-04-01 Update README.md by adding power-on-off in readme.md
2024-04-01 power-on-off added
